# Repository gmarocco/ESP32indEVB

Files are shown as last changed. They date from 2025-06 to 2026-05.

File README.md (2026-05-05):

# ESP32indEVB
ESP32-S3 industrial development board

This board is based on ESP32-S3 chip and microcontoller
 - There are the following physical communication interfaces
   
 a) debug USB (it is connected to a UARTport of ESP32-S3)  
 
 b) native USB 
 
 c) isolated CANBUS with termination resistor 
 
 d) isolated RS485 with termination resistor 
 
 - There is a 9 RGB LED matrix (WS2812B) 
 
- There are 9 ESD protected GPIOs 

 - There is a free section of testpoints for experiment 

This is the third version of the board. With respect to the second version, some nets have been renamed and stiching vias along the board perimeter have been added

  You can open and modify the project with KiCad 9 release 
  For questions, feedback or proposals you can contact me at the following email: info@pcbsemplice.com
  
 !!! It is not allowed to reproduce the board for mass production and for business purposes. If you have a business proposal you can write at the following email: info@pcbsemplice.com
 
  Are you interested in these projects and want to contribute to the development of boards and projects (including open-source), prototypes, and documentation? You can make a no-obligation donation at this PayPal link: https://shorturl.at/0LquK Every contribution, no matter how small, makes a difference. Thank you!

Scheda di sviluppo industriale ESP32-S3  
Questa scheda è basata sul chip e microcontrollore ESP32-S3 

- Sono presenti le seguenti interfacce di comunicazione fisica:
  
a) USB di debug (collegata a una porta UART dell'ESP32-S3)  

b) USB nativa 

c) CANBUS isolato con resistenza di terminazione 

d) RS485 isolata con resistenza di terminazione 

- È presente una matrice di 9 LED RGB (WS2812B)

- Sono presenti 9 GPIO con protezione ESD  

- È disponibile una sezione gratuita di testpoint per esperimenti  
È possibile aprire e modificare il progetto con KiCad versione 9  

Questa è la terza verione della scheda. Rispetto alla seconda versione sono state rinominate alcune net e sono stati aggiunti dei fori di via stiching lungo il perimetro della scheda

Per domande feedback e suggerimenti mi puoi contattare al seguente indirizzo email: info@pcbsemplice.com

!!! E' vietato riprodurre la scheda per scopi commerciali. Per proposte commerciali puoi scrivere a info@pcbsemplice.com

Se parli Italiano e stai inziando con KiCad ti segnalo il percorso KiCadSemplice (www.pcbsemplice.com/kicad)
Se sei interessato a progettare circuiti professionali , è disponibile un percorso personalizzato chiamato pcb-pro-accademy 
  -  ESP32_industrial EVB 3D model
  -  block diagram
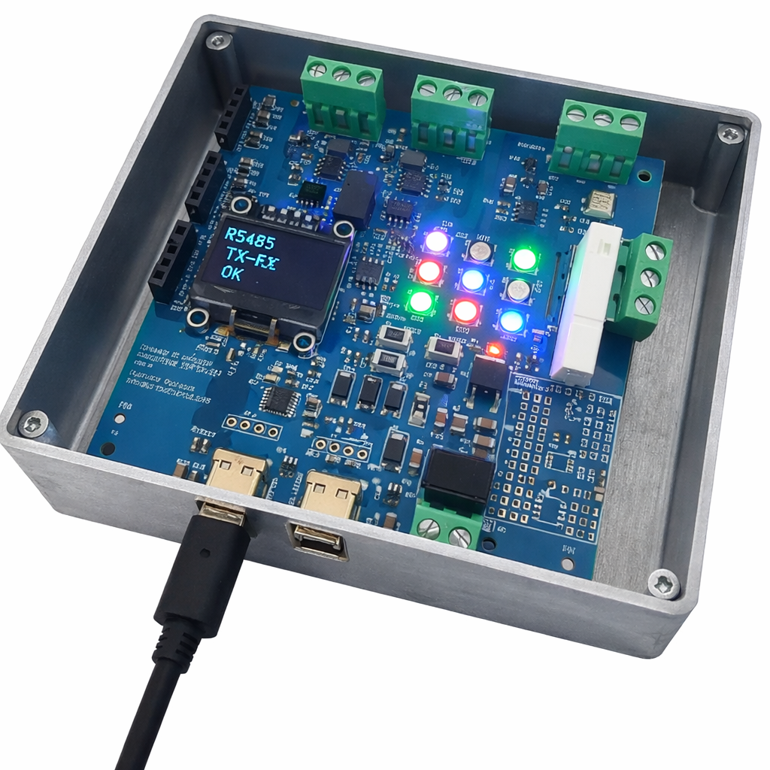
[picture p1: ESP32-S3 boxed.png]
  -  

Ti interessano questi progetti e vuoi contribuire per lo sviluppo di schede e progetti (anche open-source), prototipi, documentazione ? Puoi effettuare una donazione senza impegno a questo link di Paypal https://shorturl.at/0LquK Ogni contributo, anche piccolo, fa la differenza. Grazie!

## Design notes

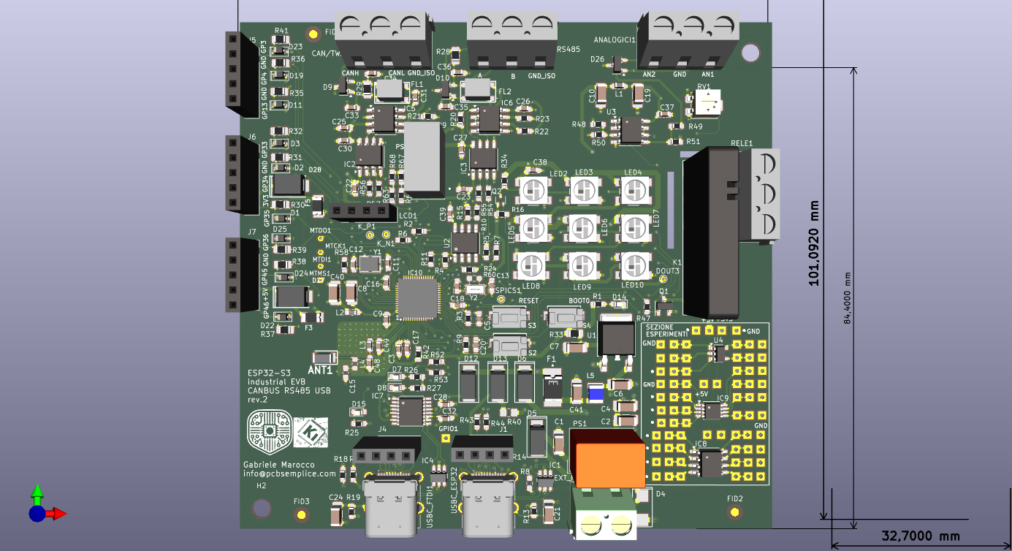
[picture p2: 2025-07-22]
3D ESP32-S3 industrial dev.board.png

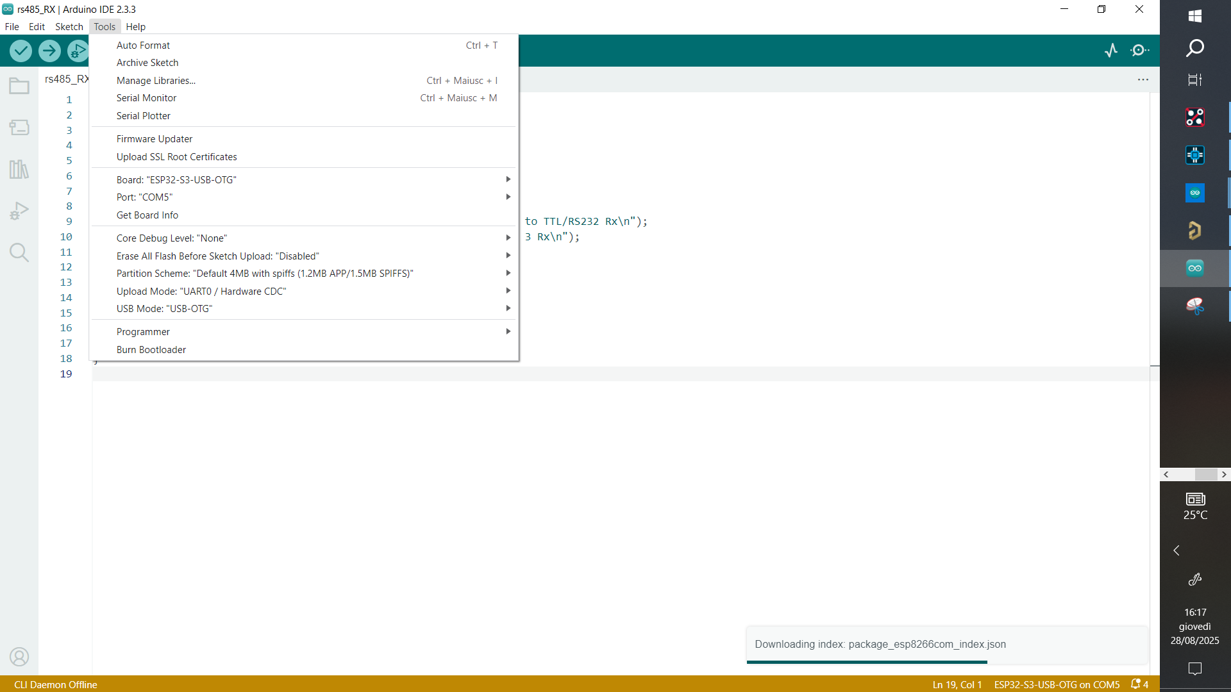
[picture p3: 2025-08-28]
Arduino examples/board configuration.png

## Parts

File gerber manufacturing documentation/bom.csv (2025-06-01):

Designator | Footprint | Quantity | Value | LCSC Part #
ANALOGICI1, CAN1, RELE1, RS1 | TerminalBlock_bornier-3_P5.08mm | 4 | 282837-3
ANT1 | ANTC3216X130N | 1 | RFANT3216120A5T
C1, C2, C4 | 1206 | 3 | 10uF_50V
C10, C19, C40, C41, C6, C7, C8 | 1206 | 7 | 10uF 50V
C11, C12 | 0603 | 2 | 20pF
C13, C14 | 0603 | 2 | 30pF
C15, C48, C49 | 0603 | 3 | 1p8F
C16, C17, C18, C20, C22, C23, C25, C26, C27, C28, C29, C3, C30, C32, C37, C38, C39, C9 | 0603 | 18 | 100nF
C21, C24 | 1206 | 2 | 3n3F 1kV
C31, C33, C34, C35, C36 | 0603 | 5 | 100PF
C5 | 0603 | 1 | 1uF
D1, D11, D19, D2, D22, D23, D24, D25, D3 | SOD-323 | 9 | ESD7351HT1G
D10, D26, D9 | SOT-23-3 | 3 | PESD2CANFD27L-TR
D12, D13, D5, D6 | SMA | 4 | CDBA340-HF
D14, D15, D7, D8 | 0603 | 4 | LED
D27 | DIOM5436X244N | 1 | SMBJ5.0A
D28 | DIOM5436X244N | 1 | SMBJ3V3-E3/5B
D4 | DIOM5436X261N | 1 | SMBJ36CA
DOUT3, K_N1, K_P1, MTCK1, MTDI1, MTDO1, MTMS1, SPICS1 | TestPoint_THTPad_D1.0mm_Drill0.5mm | 8 | TestPoint
EXT_POWER1 | 2828372 | 1 | 282837-2
F1 | 1812L010DR | 1 | 1812L150_24MR
F3, F5 | 1206L05015YR | 2 | 1206L050_15YR
FID1, FID2, FID3 | Fiducial_1.5mm_Mask3mm | 3 | Fiducial
FL1, FL2 | ACT45B1012PTL003 | 2 | ACT45B-101-2P-TL003
H1, H2 | MountingHole_3.2mm_M3 | 2 | MountingHole
IC1, IC4 | SOT23-6 | 2 | USBLC6-2SC6
IC10 | QFN40P700X700X90-57N-D | 1 | ESP32-S3FN8
IC2, IC3 | SO-8_3.9x4.9mm_P1.27mm | 2 | ADUM3201ARZ-RL7
IC5 | SO-8_3.9x4.9mm_P1.27mm | 1 | MCP2562-E_SN
IC6 | SO-8_3.9x4.9mm_P1.27mm | 1 | MAX13488EESA+T
IC7 | TSSOP-16_4.4x5mm_P0.65mm | 1 | FT230XS-R
IC8 | SO-8_3.9x4.9mm_P1.27mm | 1 | NE555DR
IC9 | MSOP-8_3x3mm_P0.65mm | 1 | NE555DR
J1, J4 | PinHeader_1x04_P2.54mm_Vertical | 2 | Conn_01x04_Pin
J5, J6, J7 | PinSocket_1x05_P2.54mm_Vertical | 3 | Conn_01x05_Socket
K1 | Relay_SPDT_Finder_34.51_Vertical | 1 | FINDER-34.51
L1, L2 | 0603 | 2 | BLM18AG102SN1D
L3, L4 | 0603 | 2 | 2n4H
L5 | 1277ASH100MP2 | 1 | DFE322512F-4R7M=P2
LCD1 | PinHeader_1x04_P2.54mm_Vertical | 1 | SSD1306
LED10, LED2, LED3, LED4, LED5, LED6, LED7, LED8, LED9 | WS2812B | 9 | WS2812B
PS1 | Converter_DCDC_TRACO_TSR-1_THT | 1 | TSR_1-2450
PS2 | TEA10505 | 1 | TEA_1-0505
Q1 | SOT-23-3 | 1 | DRDC3105F-7
Q2 | SOT-523 | 1 | DMG1012T
R1, R20, R22, R23 | 0603 | 4 | 1K
R10, R11, R2, R24, R43, R44, R47, R52, R53, R54, R55, R56, R57, R58, R6, R63, R64, R7 | 0603 | 18 | 0R
R12, R14, R17, R18 | 0603 | 4 | 5k1
R13, R19 | 0603 | 2 | 1M
R15, R3, R4, R42, R5, R9 | 0603 | 6 | 100K
R16 | 0603 | 1 | 2k2
R21, R25, R26, R27 | 0603 | 4 | 470R
R28, R29 | 0805 | 2 | 120R
R30, R31, R32, R35, R36, R37, R38, R39, R41 | 0805 | 9 | 49R9
R33, R40 | 0805 | 2 | 0R 0.5W 0805
R34, R50, R51 | 0603 | 3 | 4k7
R48, R49 | 0603 | 2 | 47k
R60 | 0603 | 1 | 5M
R67, R68, R8 | 0603 | 3 | 1k5
RV1 | Potentiometer_Bourns_3314G_Vertical | 1 | 10k
S2, S3, S4 | EVQPE104K | 3 | EVQ-PE104K
TP1, TP10, TP11, TP12, TP13, TP14, TP15, TP16, TP17, TP18, TP19, TP2, TP20, TP21, TP22, TP23, TP24, TP25, TP26, TP27, TP28, TP29, TP3, TP30, TP31, TP32, TP33, TP34, TP35, TP36, TP37, TP38, TP39, TP4, TP40, TP41, TP42, TP43, TP44, TP45, TP46, TP47, TP48, TP49, TP5, TP50, TP51, TP52, TP53, TP54, TP55, TP56, TP57, TP58, TP59, TP6, TP60, TP61, TP62, TP63, TP64, TP65, TP66, TP67, TP68, TP69, TP7, TP70, TP71, TP72, TP8, TP9 | TestPoint_Pad_through hole 1.5mm | 72 | TestPoint
U1 | TO-252-2 | 1 | NCP1117-3.3_TO252
U2 | SOIC-8_3.9x4.9mm_P1.27mm | 1 | W25Q80DVSNIG
U3 | SO-8_3.9x4.9mm_P1.27mm | 1 | LMV358IDR
U4 | SOT-23-5 | 1 | NCP718xSN180
USBC_ESP32, USBC_FTDI1 | UJ31CHG2SMTTR | 2 | UJ31-CH-G2-SMT-TR
Y1 | FL4000157Z | 1 | FL4000157Z
Y2 | ABS07AIG | 1 | ABS07AIG-32.768KHZ-D-T

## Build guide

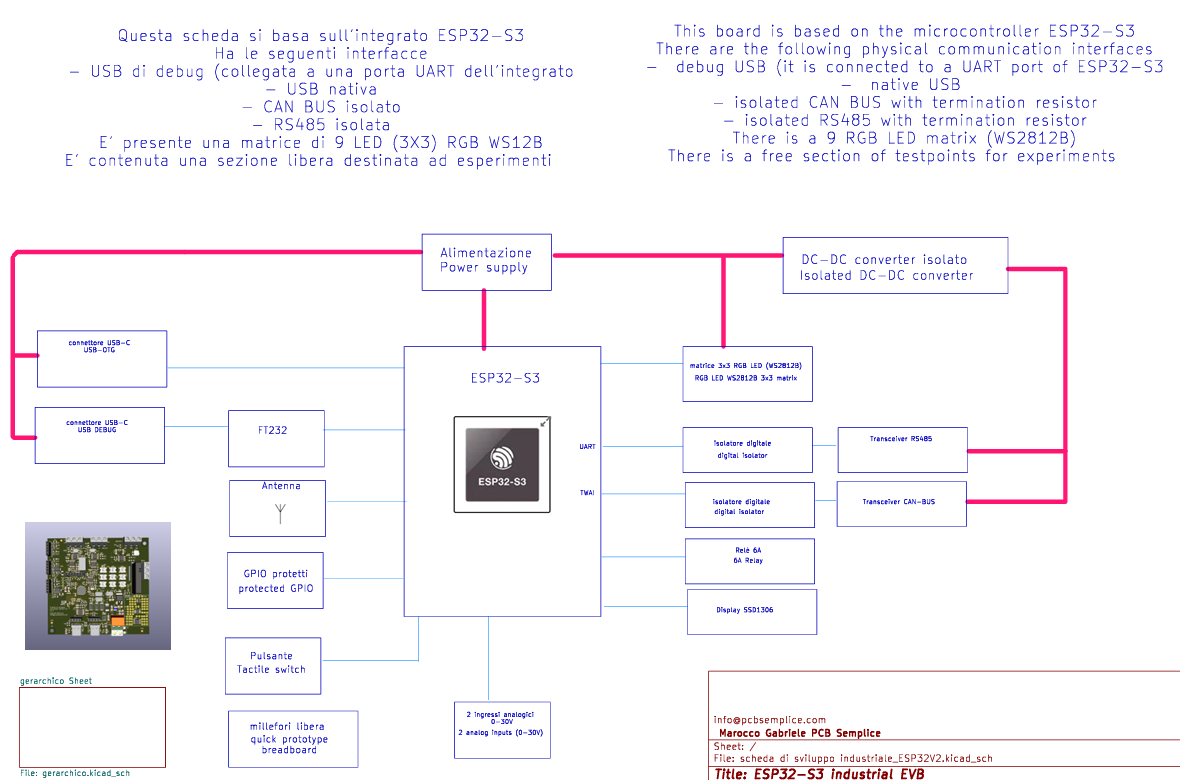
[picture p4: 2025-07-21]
gerber manufacturing documentation/block diagram.png

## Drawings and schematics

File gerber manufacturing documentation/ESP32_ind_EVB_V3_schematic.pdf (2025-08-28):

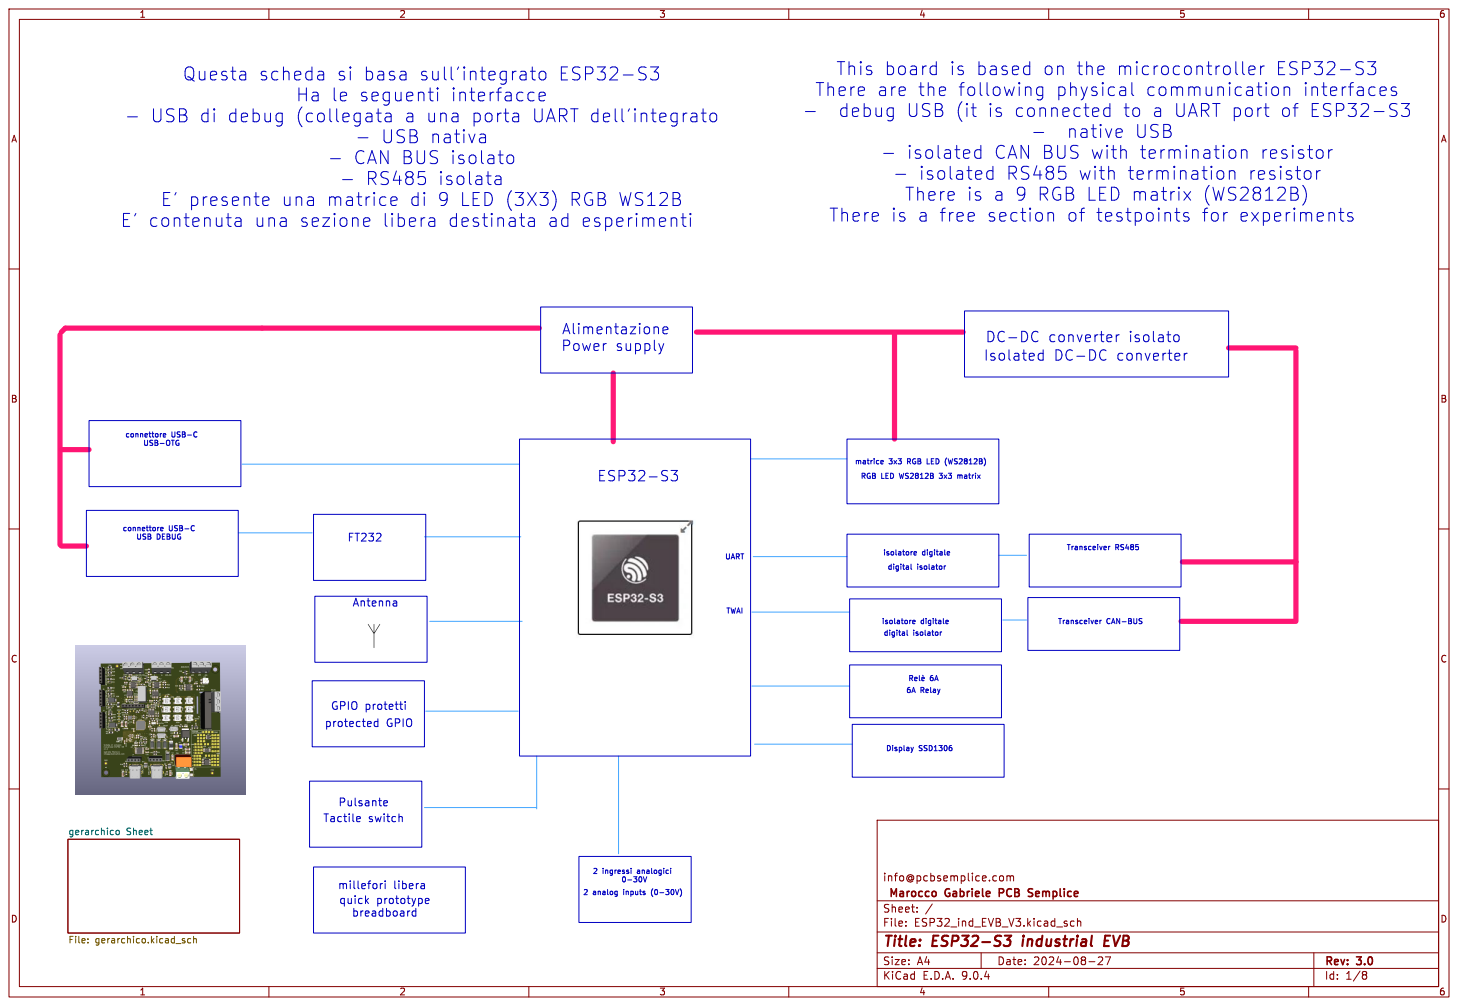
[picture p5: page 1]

- debug USB (it is connected to a UART port of ESP32-S3

There is a 9 RGB LED matrix (WS2812B)

DC-DC converter isolato

þÿRelè6A Power supply Antenna

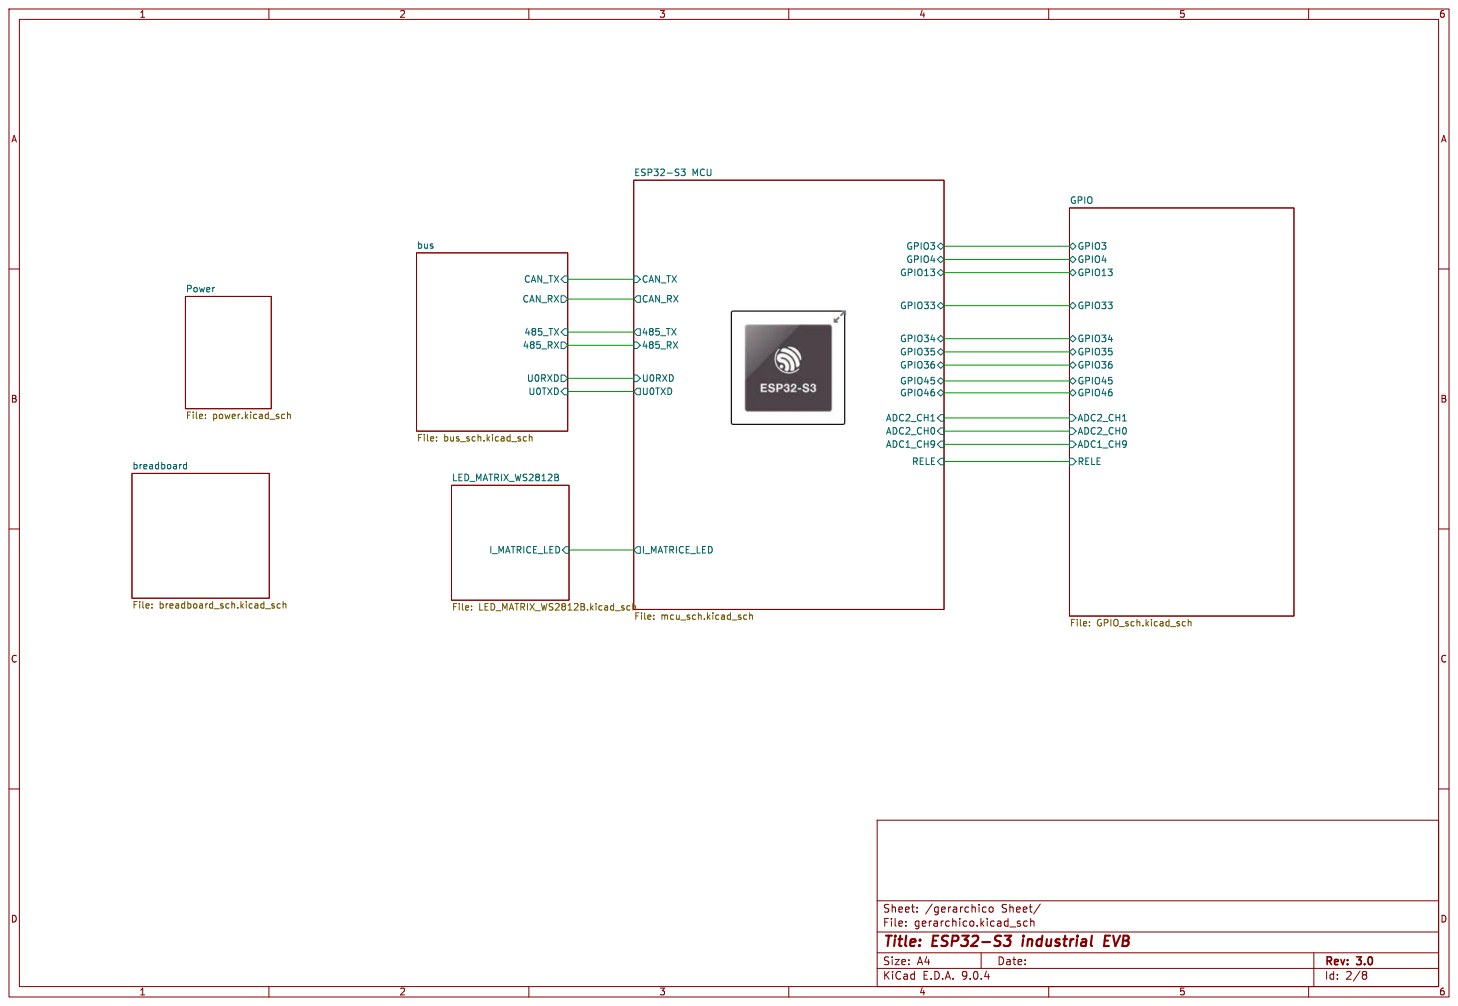
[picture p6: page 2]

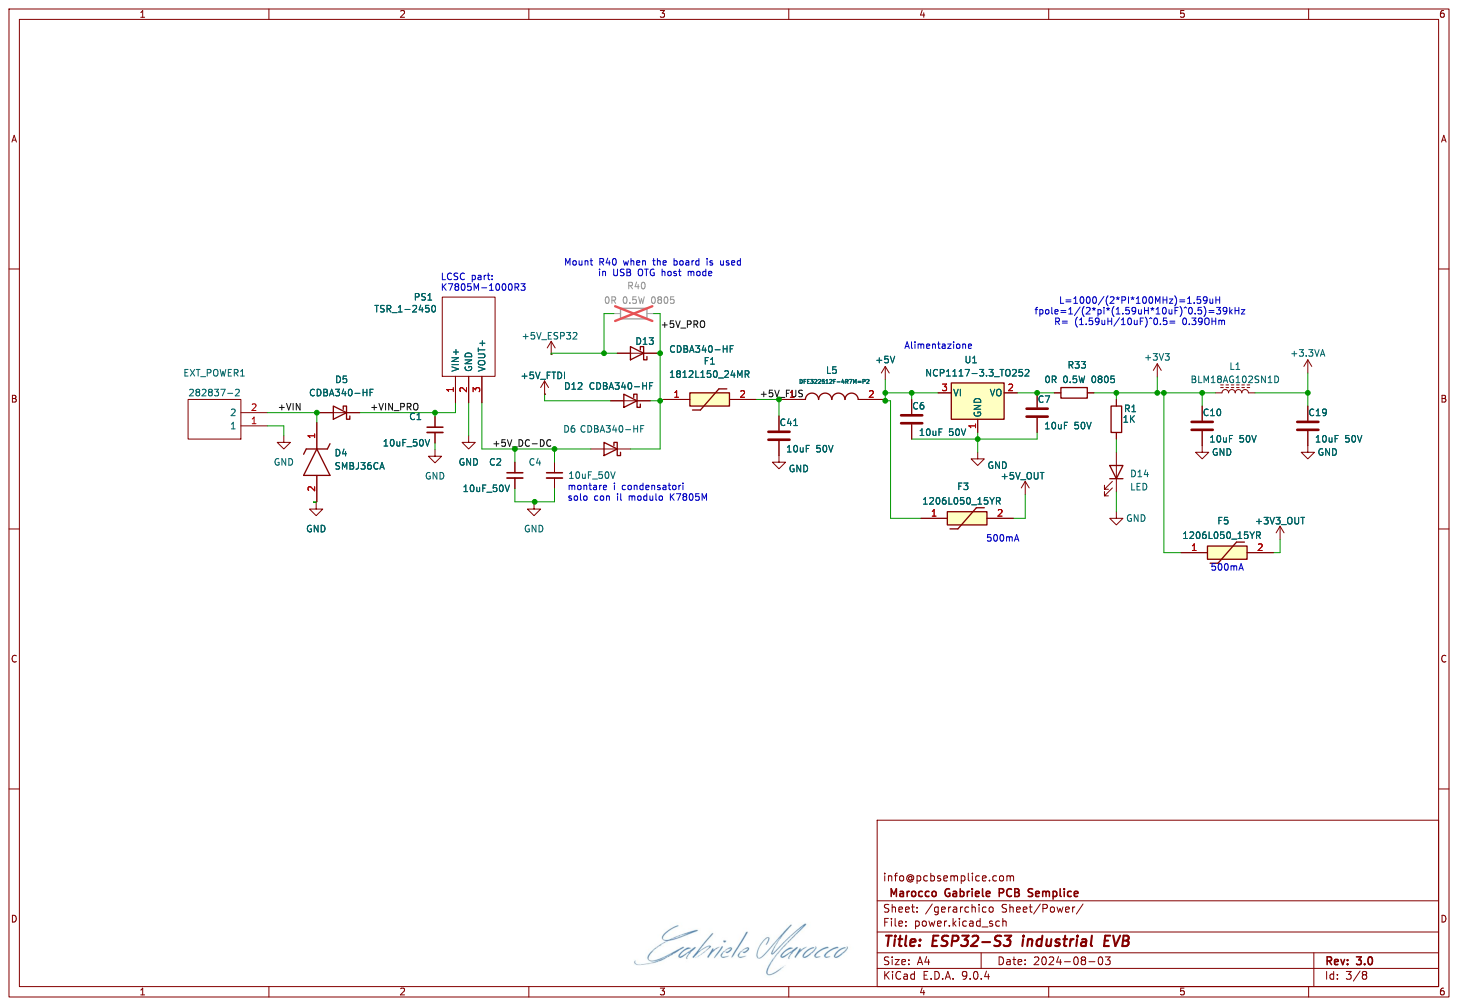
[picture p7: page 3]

500mA Mount R40 when the board is used
+5V_ESP32 C4

in USB OTG host mode

montare i condensatori solo con il modulo K7805M

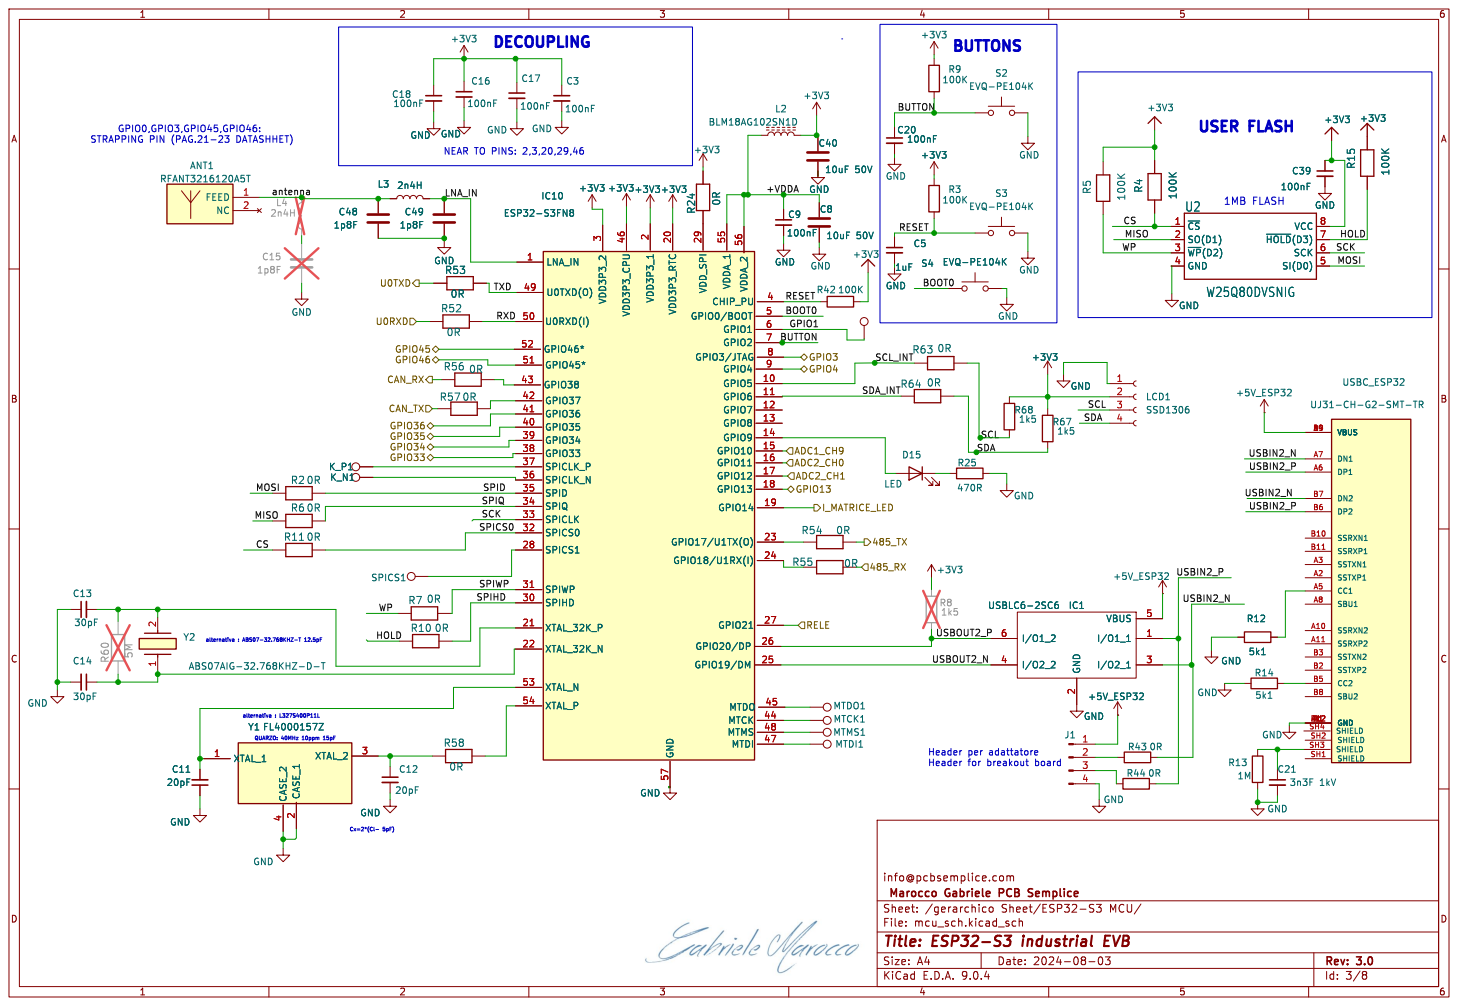
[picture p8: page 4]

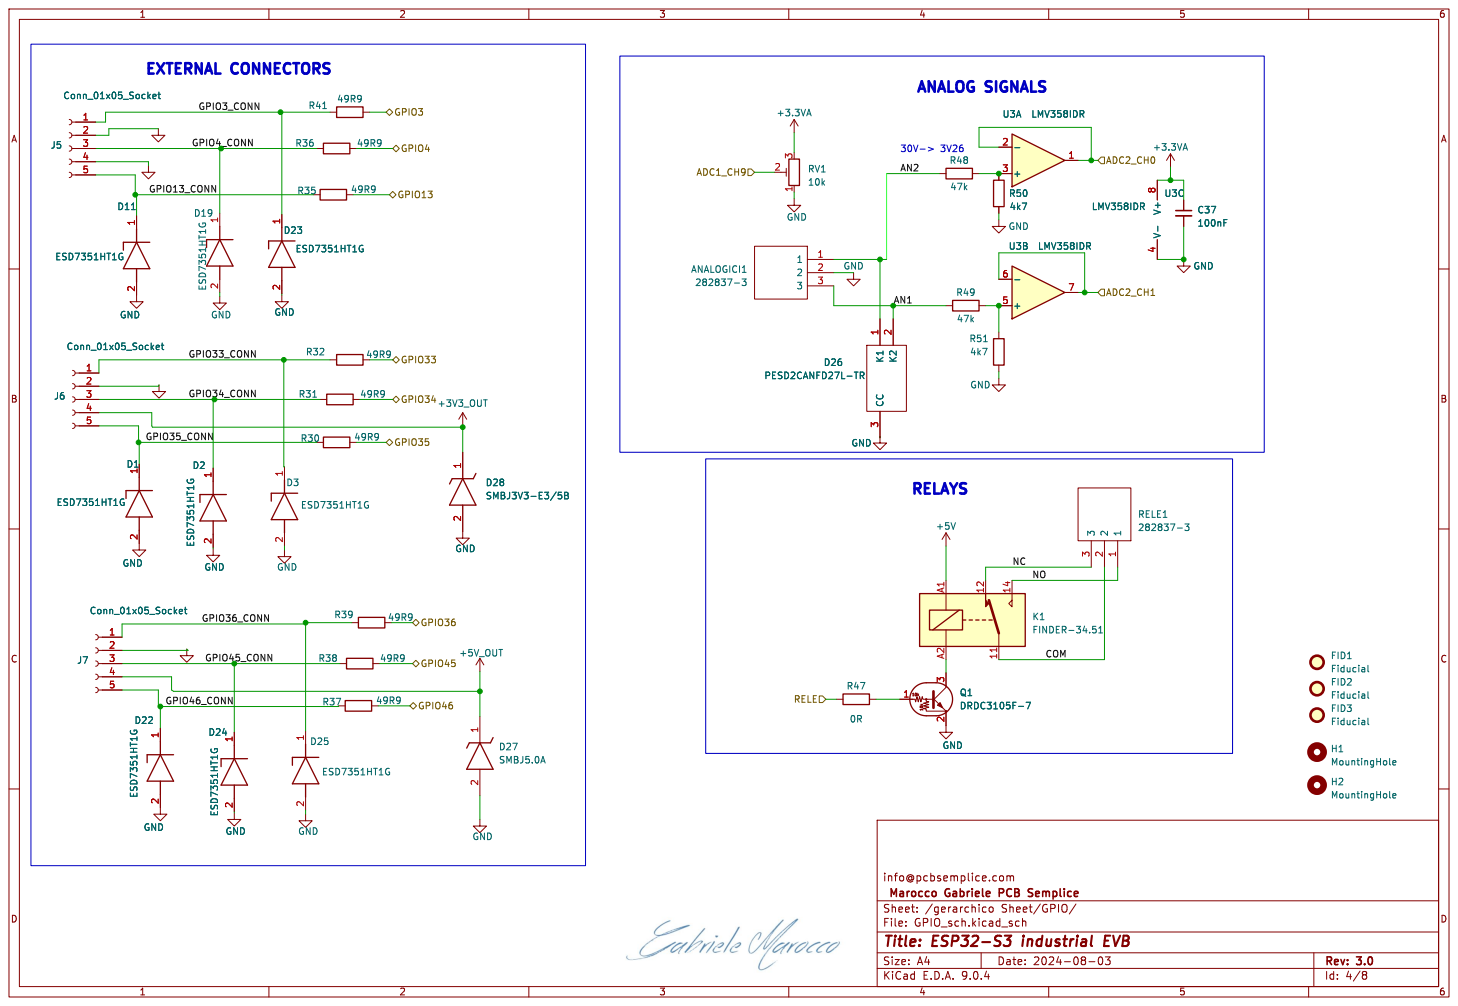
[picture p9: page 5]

FID2 Fiducial H1 MountingHole FID1 Fiducial H2 MountingHole FID3 Fiducial

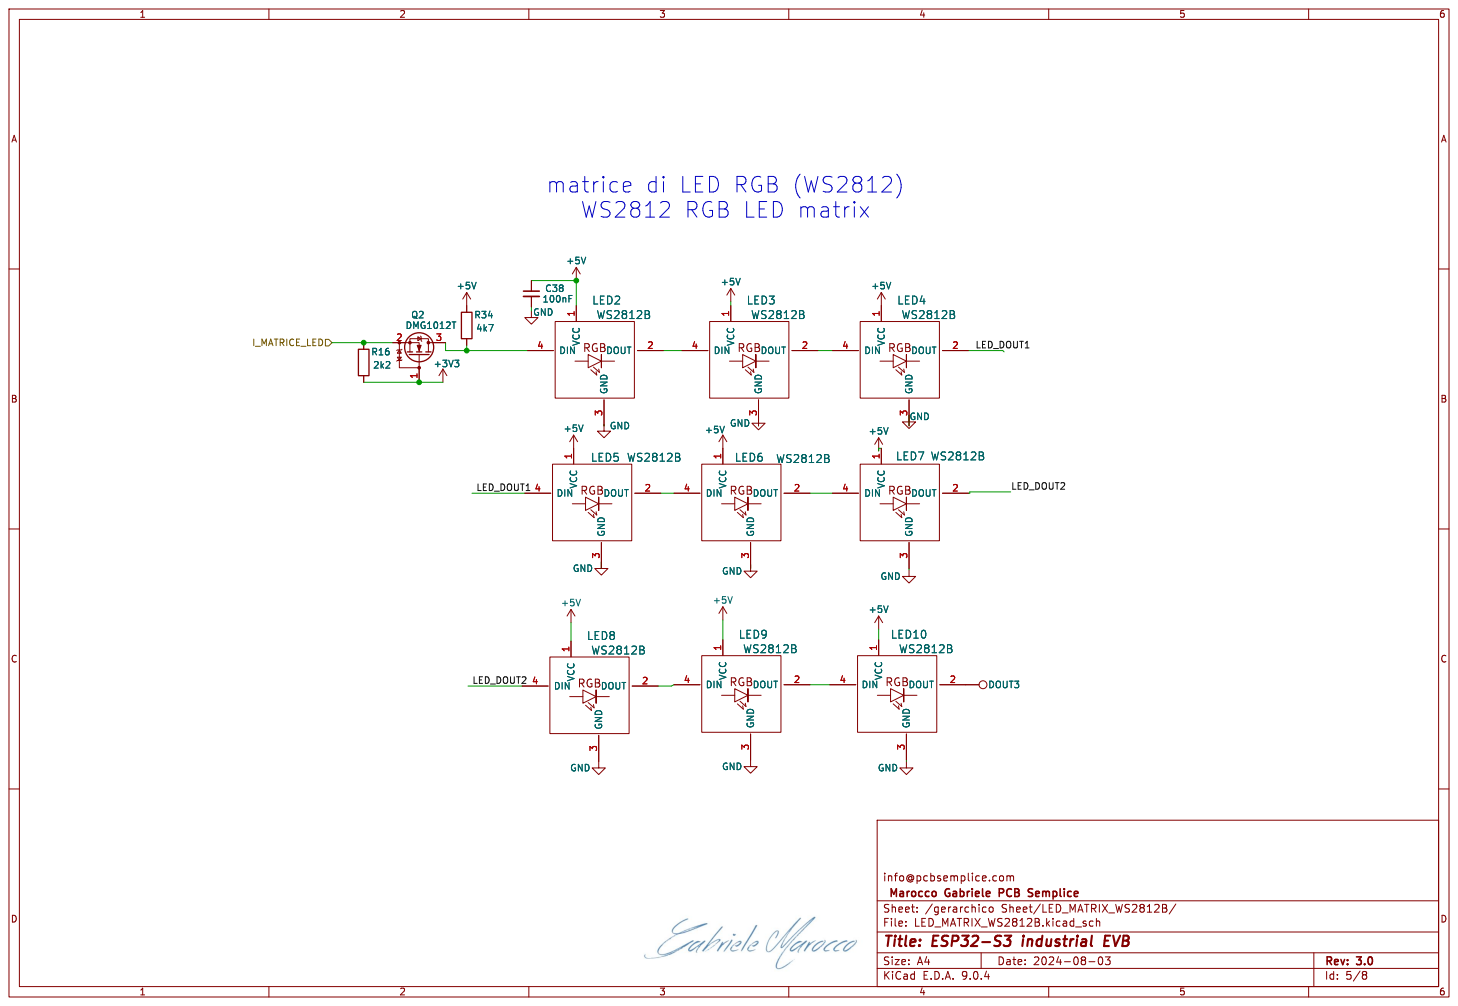
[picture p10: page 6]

LED_DOUT1 matrice di LED RGB (WS2812)
WS2812 RGB LED matrix

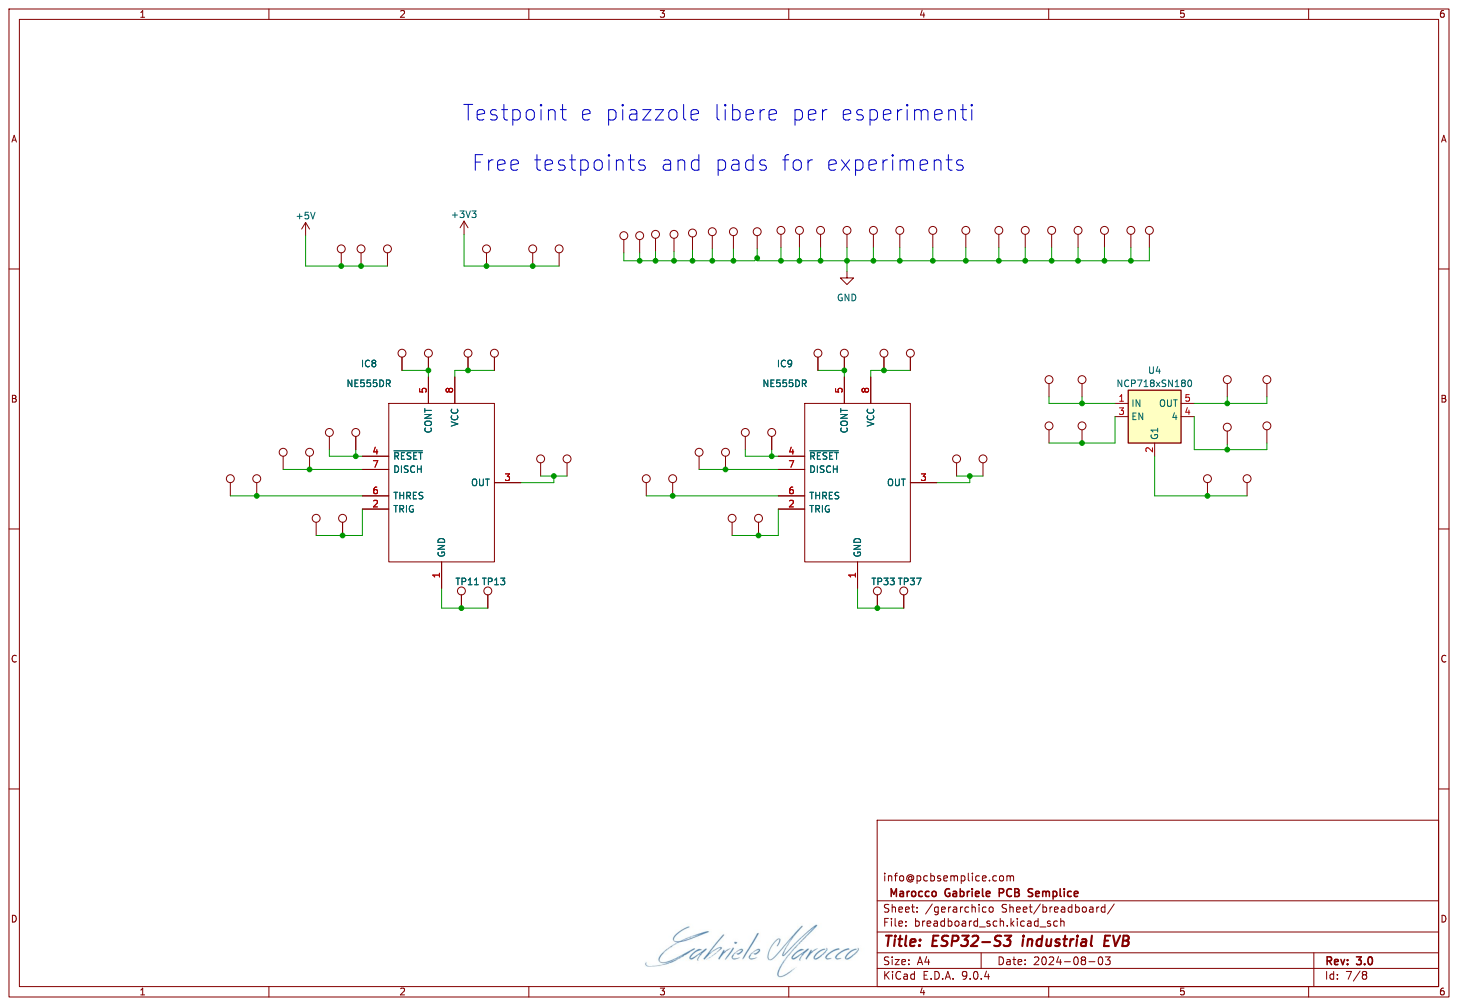
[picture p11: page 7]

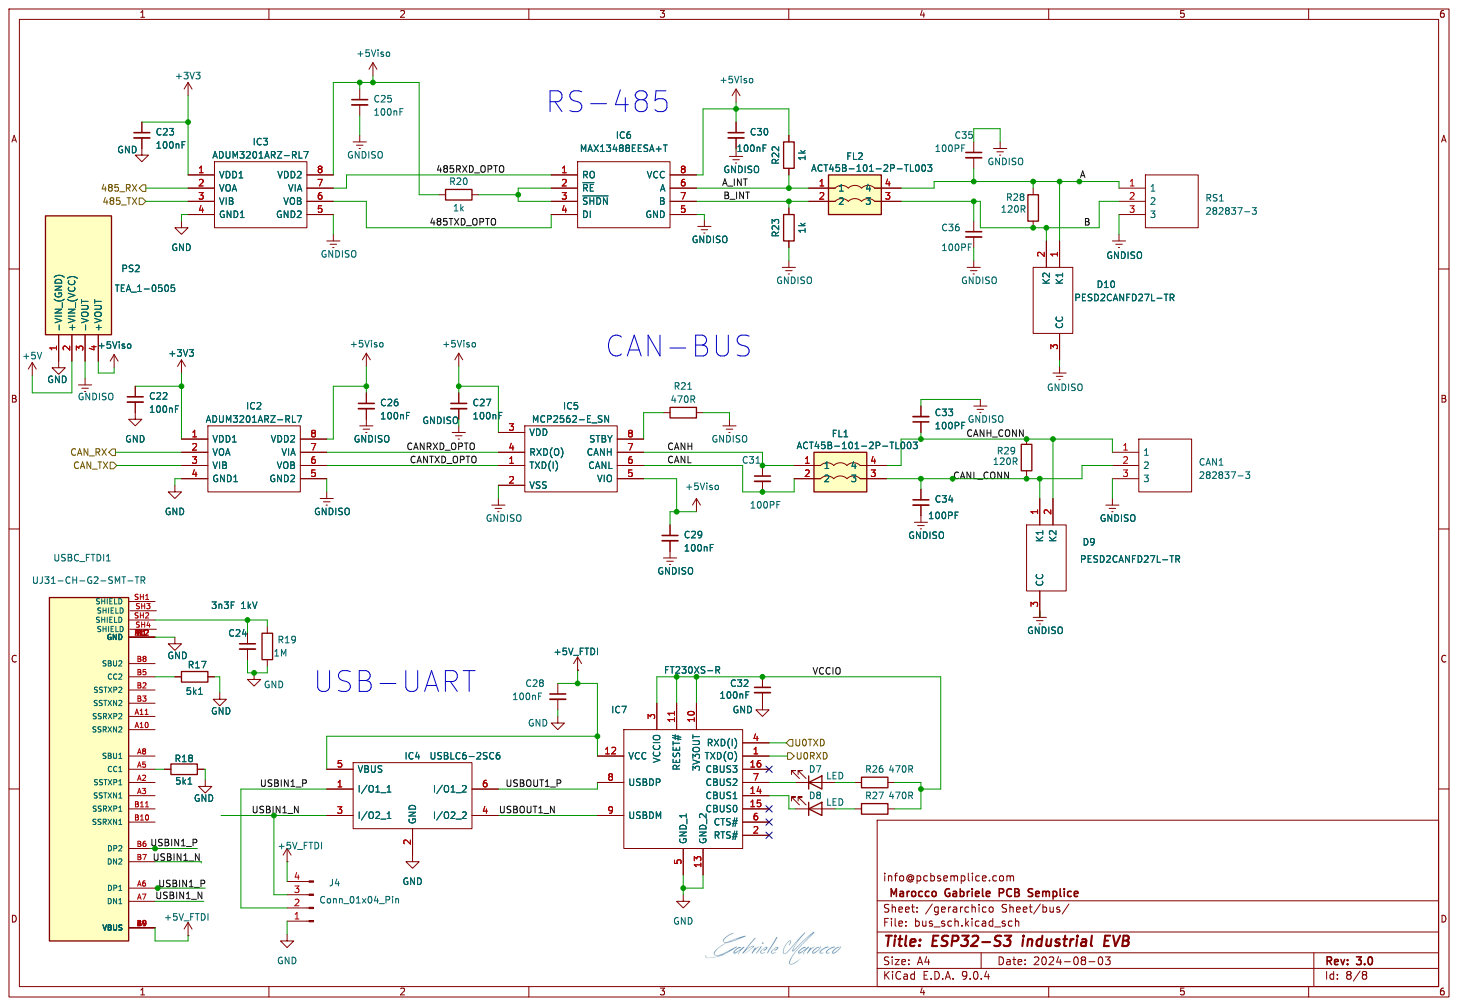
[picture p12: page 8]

5 3V3OUT 10 GND_2 13 CBUS3 16 CBUS2 7 CBUS1 14 CBUS0 15 CTS# 6 RTS# 2 RESET# 11 RXD(I) 4 TXD(O) 1 C32

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

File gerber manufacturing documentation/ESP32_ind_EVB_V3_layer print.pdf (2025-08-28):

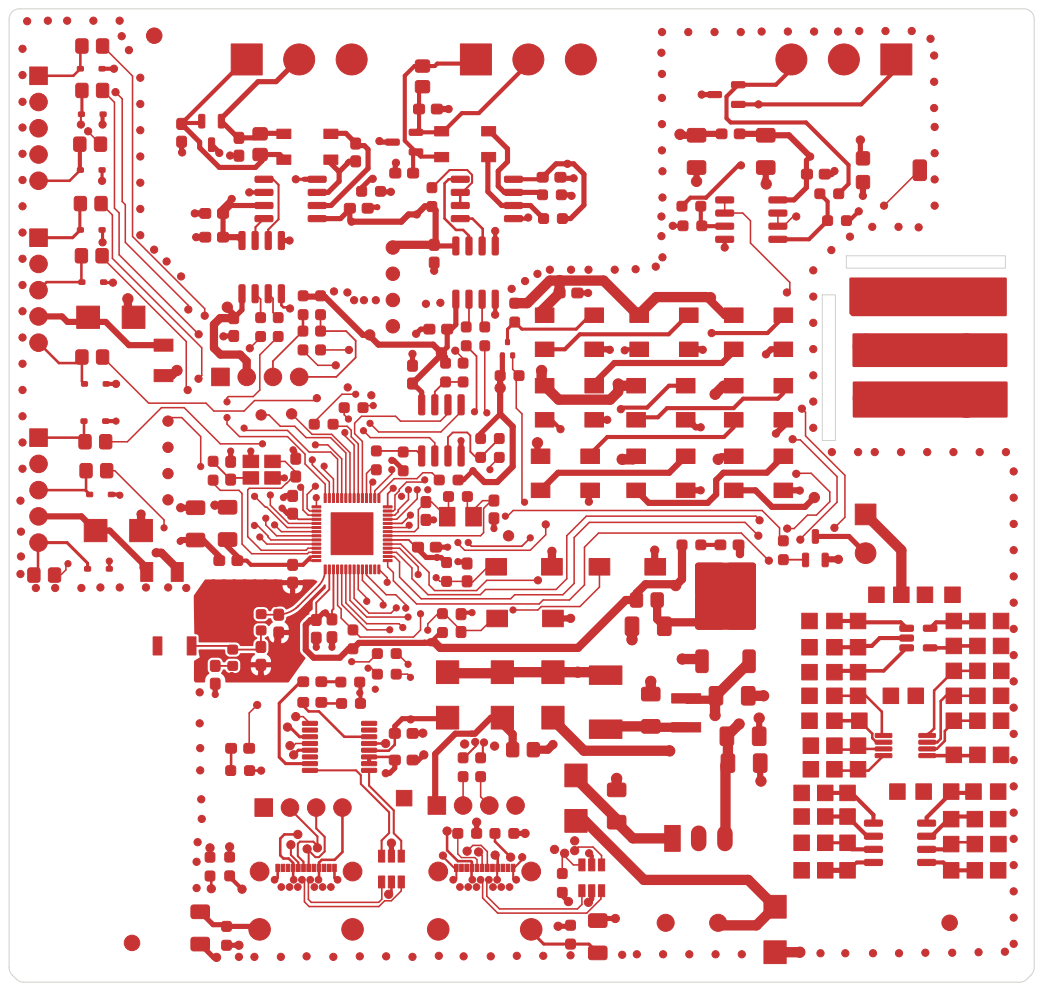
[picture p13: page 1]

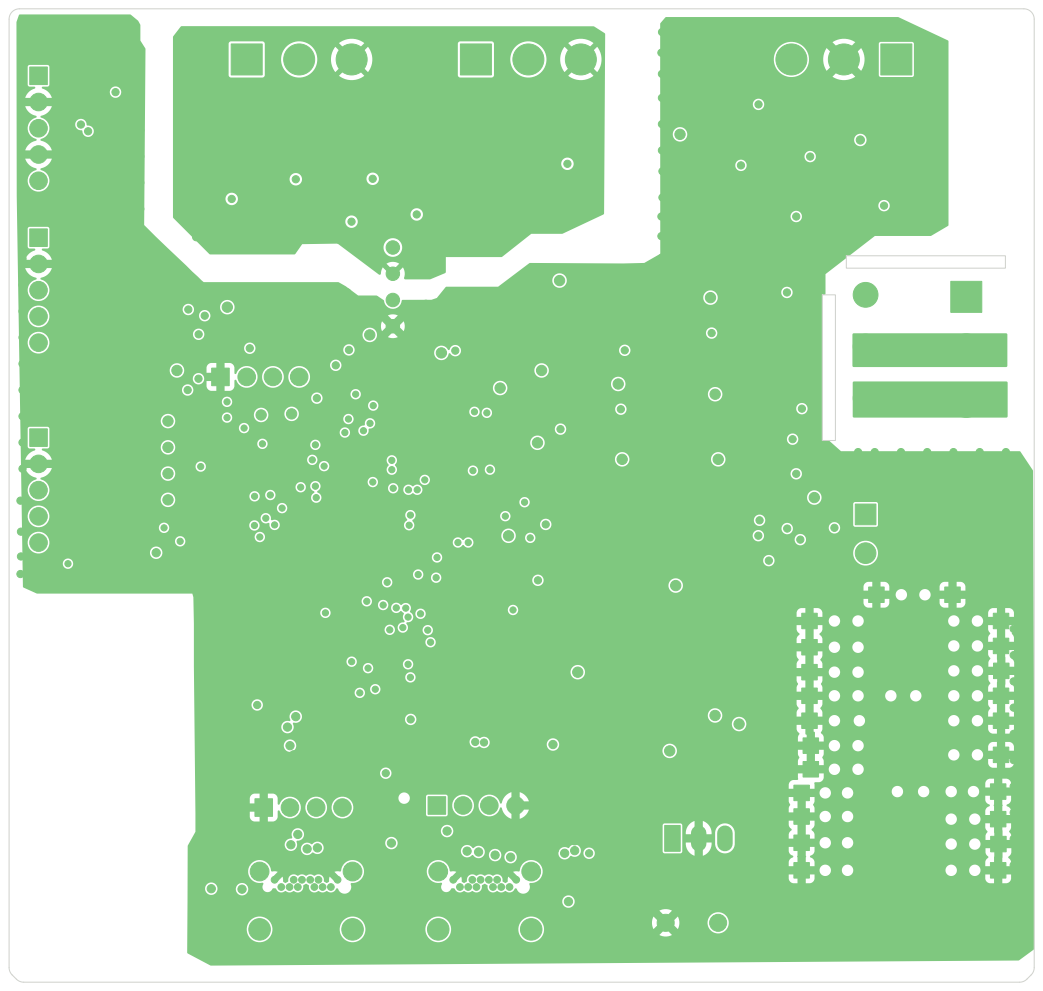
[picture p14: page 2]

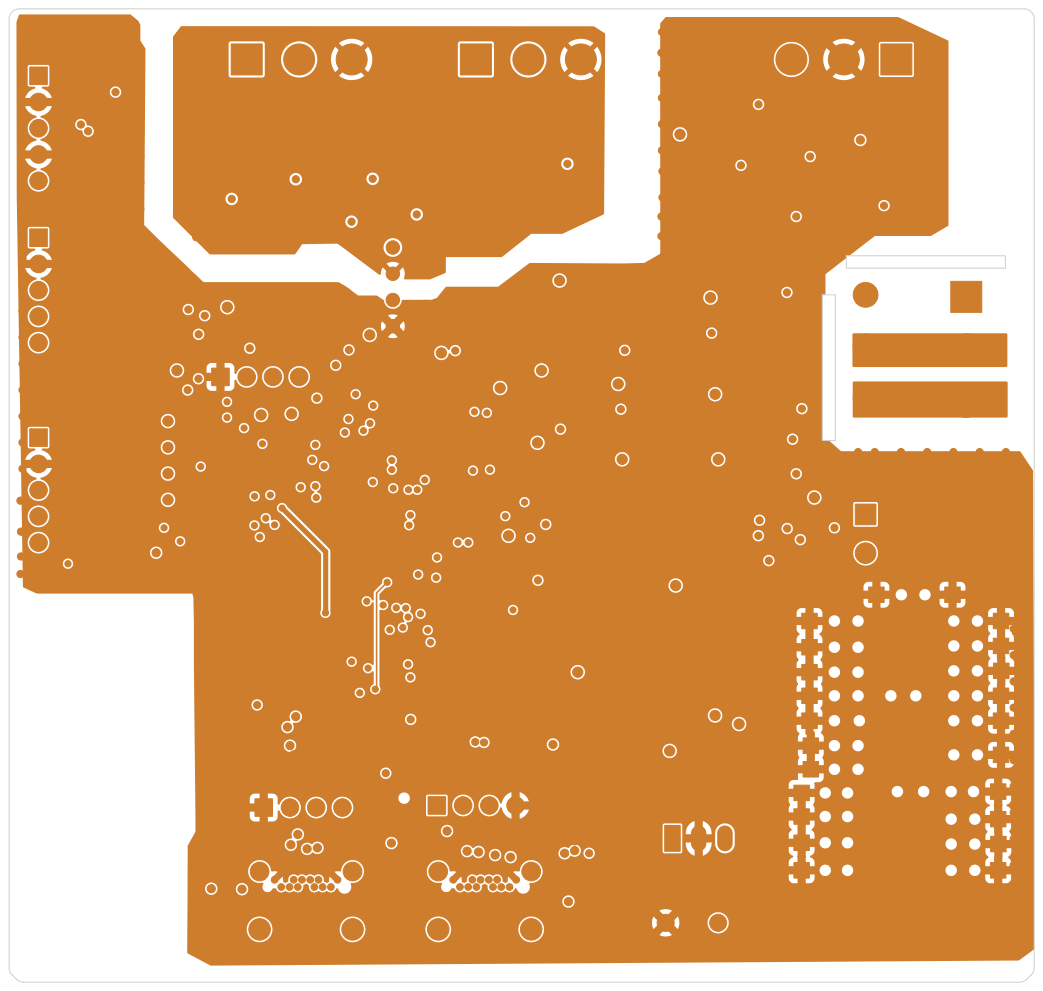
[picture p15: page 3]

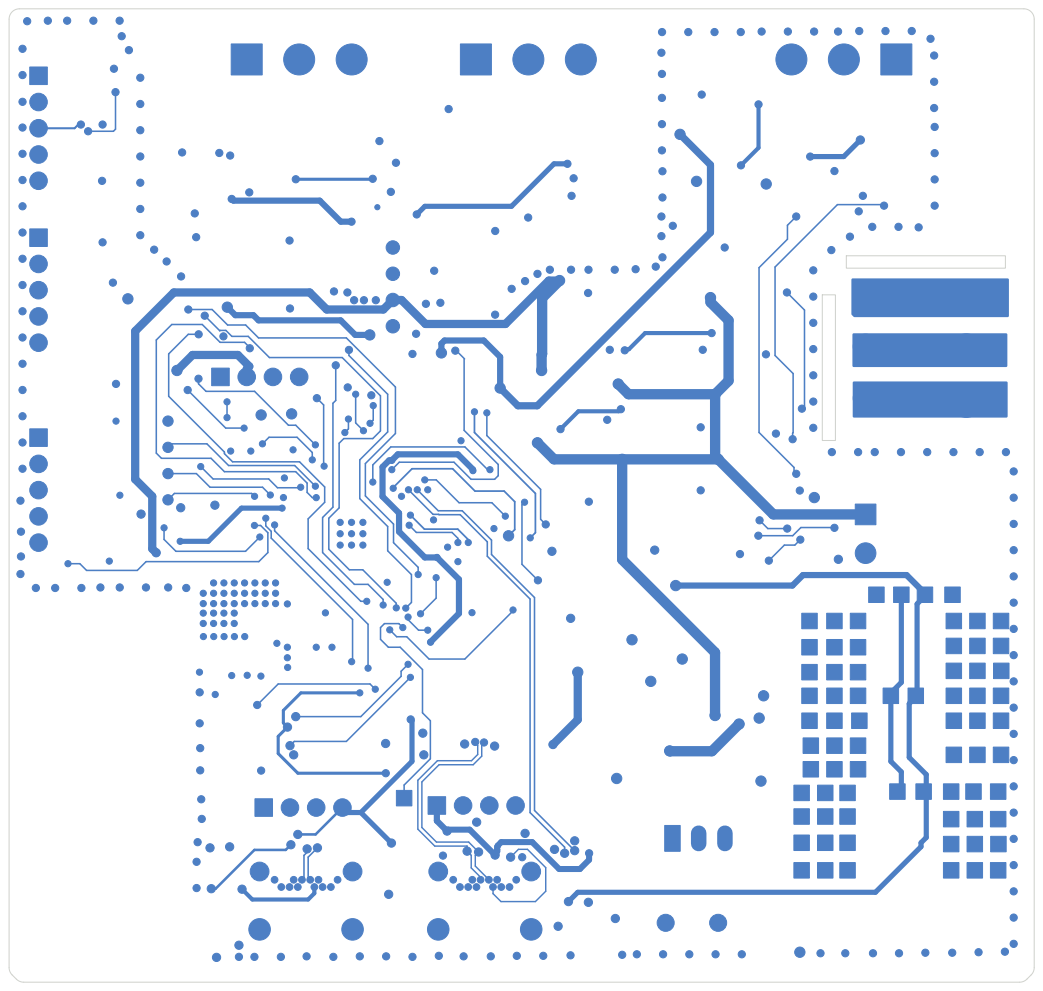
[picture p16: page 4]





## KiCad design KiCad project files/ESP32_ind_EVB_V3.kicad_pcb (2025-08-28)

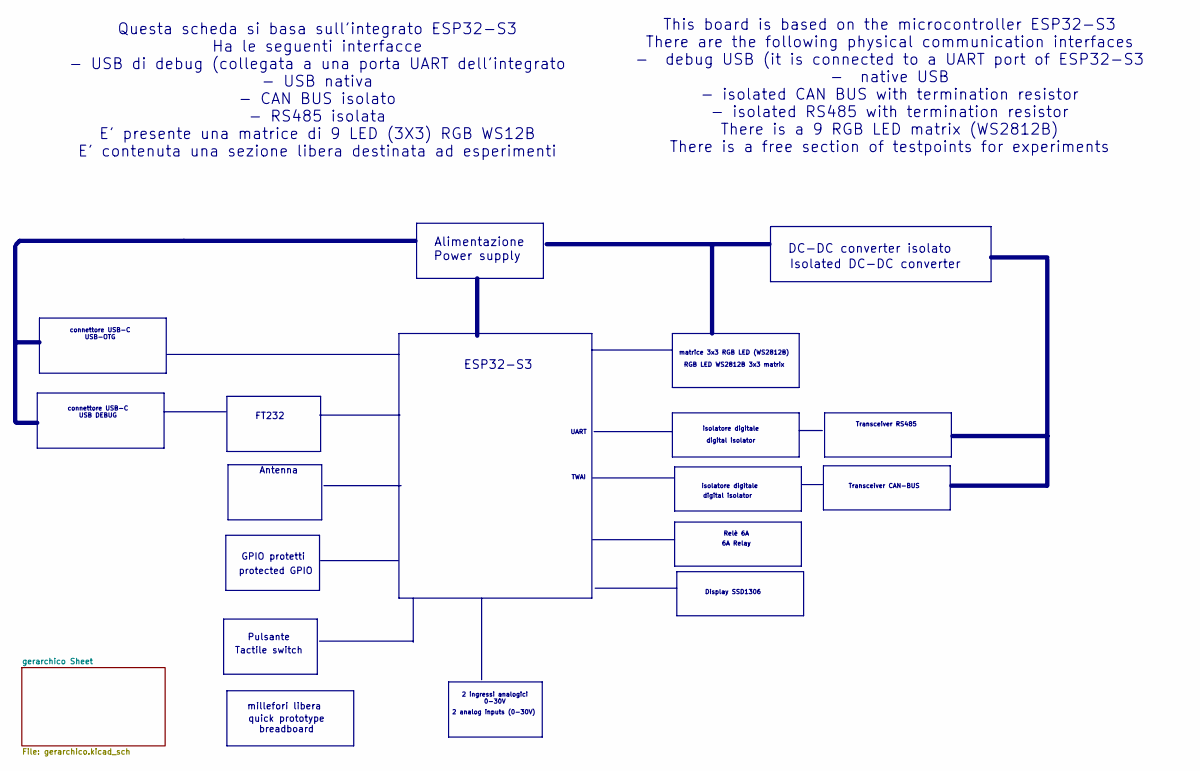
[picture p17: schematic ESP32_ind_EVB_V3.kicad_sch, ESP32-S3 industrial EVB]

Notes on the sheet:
TWAI
FT232
isolatore digitale
Transceiver RS485
matrice 3x3 RGB LED (WS2812B)
This board is based on the microcontroller ESP32-S3 There are the following physical communication interfaces - debug USB (it is connected to a UART port of ESP32-S3 - native USB - isolated CAN BUS with termination resistor - isolated RS485 with termination resistor There is a 9 RGB LED matrix (WS2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
Alimentazione
GPIO protetti
ESP32-S3
Transceiver CAN-BUS
millefori libera
Power supply
quick prototype breadboard
Questa scheda si basa sull'integrato ESP32-S3 Ha le seguenti interfacce - USB di debug (collegata a una porta UART dell'integrato - USB nativa - CAN BUS isolato - RS485 isolata E' presente una matrice di 9 LED (3X3) RGB WS12B E' contenuta una sezione libera destinata ad esperimenti
6A Relay
digital isolator
Pulsante
connettore USB-C USB-OTG
DC-DC converter isolato
Display SSD1306
Isolated DC-DC converter
2 analog inputs (0-30V)
protected GPIO
RGB LED WS2812B 3x3 matrix
Antenna
Relè 6A
2 ingressi analogici 0-30V
connettore USB-C USB DEBUG
Tactile switch
UART

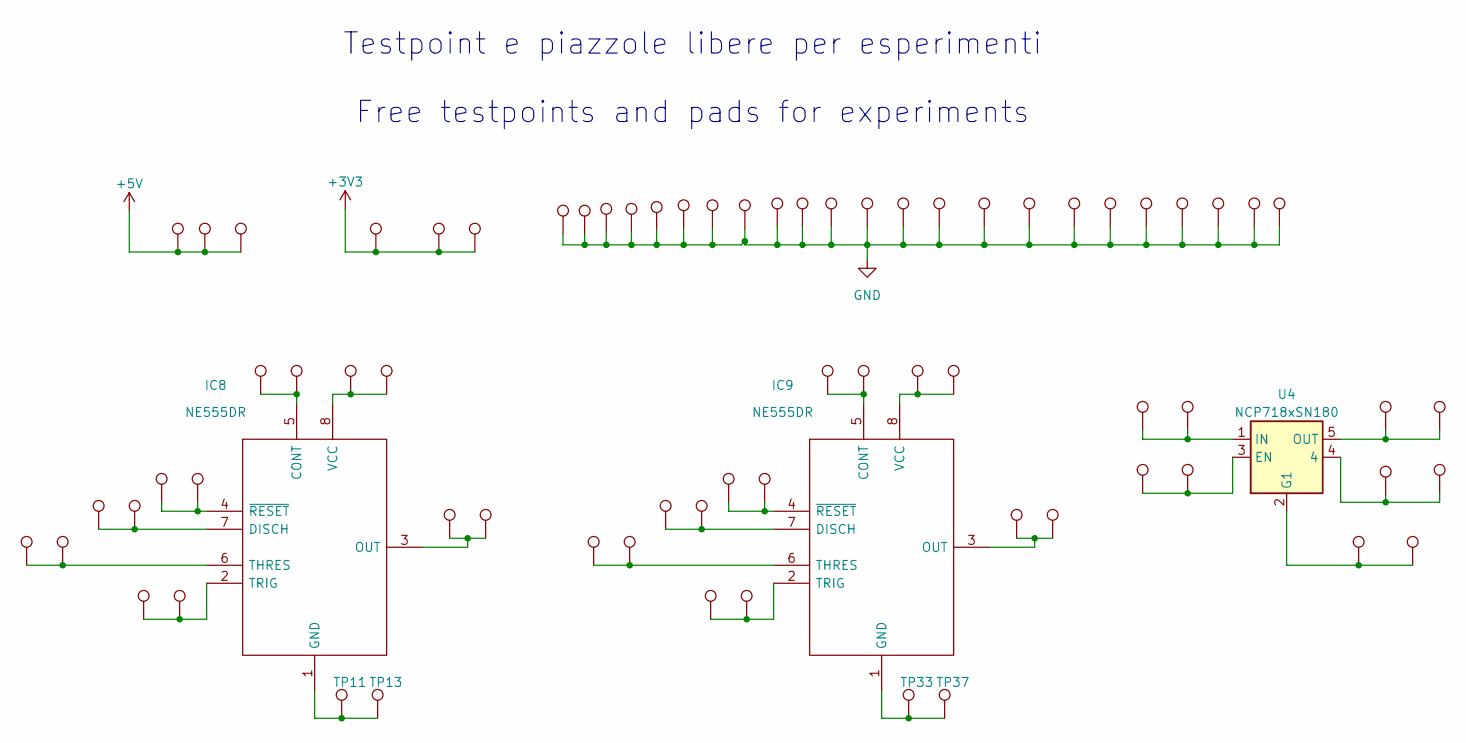
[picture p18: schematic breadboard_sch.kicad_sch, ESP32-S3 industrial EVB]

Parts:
IC8: NE555DR; SO-8_3.9x4.9mm_P1.27mm; Manufacturer_Part_Number NE555DR; Mouser Part Number 595-NE555DR
IC9: NE555DR; MSOP-8_3x3mm_P0.65mm; Manufacturer_Part_Number NE555DR; Mouser Part Number 595-NE555DR
TP1, TP2, TP3, TP4, TP5, TP6, TP7, TP8, TP9, TP10, TP11, TP12, TP13, TP14, TP15, TP16, TP17, TP18, TP19, TP20, TP21, TP22, TP23, TP24, TP25, TP26, TP27, TP28, TP29, TP30, TP31, TP32, TP33, TP34, TP35, TP36, TP37, TP38, TP39, TP40, TP41, TP42, TP43, TP44, TP45, TP46, TP47, TP48, TP49, TP50, TP51, TP52, TP53, TP54, TP55, TP56, TP57, TP58, TP59, TP60, TP61, TP62, TP63, TP64, TP65, TP66, TP67, TP68, TP69, TP70, TP71: TestPoint; TestPoint_Pad_through hole 1.5mm
U4: NCP718xSN180; SOT-23-5

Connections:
+3V3: TP25.1, TP29.1, TP30.1; also elsewhere on the board
+5V: TP17.1, TP18.1, TP19.1; also elsewhere on the board
GND: TP34.1, TP36.1, TP38.1, TP40.1, TP41.1, TP43.1, TP45.1, TP46.1, TP47.1, TP50.1, TP51.1, TP54.1, TP55.1, TP56.1, TP57.1, TP59.1, TP63.1, TP66.1, TP67.1, TP68.1, TP69.1, TP70.1, TP71.1; also elsewhere on the board
unnamed: IC8.5 (CONT), TP9.1, TP10.1
unnamed: IC8.7 (DISCH), TP3.1, TP4.1
unnamed: IC8.1 (GND), TP11.1, TP13.1
unnamed: IC8.3 (OUT), TP15.1, TP16.1
unnamed: IC8.6 (THRES), TP1.1, TP2.1
unnamed: IC8.2 (TRIG), TP5.1, TP7.1
unnamed: IC8.8 (VCC), TP12.1, TP14.1
unnamed: IC8.4 (~RESET), TP6.1, TP8.1
unnamed: IC9.5 (CONT), TP31.1, TP32.1
unnamed: IC9.7 (DISCH), TP22.1, TP23.1
unnamed: IC9.1 (GND), TP33.1, TP37.1
unnamed: IC9.3 (OUT), TP42.1, TP44.1
unnamed: IC9.6 (THRES), TP20.1, TP21.1
unnamed: IC9.2 (TRIG), TP24.1, TP27.1
unnamed: IC9.8 (VCC), TP35.1, TP39.1
unnamed: IC9.4 (~RESET), TP26.1, TP28.1
unnamed: TP61.1, TP65.1, U4.4
unnamed: TP49.1, TP53.1, U4.3 (EN)
unnamed: TP58.1, TP62.1, U4.2 (G1)
unnamed: TP48.1, TP52.1, U4.1 (IN)
unnamed: TP60.1, TP64.1, U4.5 (OUT)

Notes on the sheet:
Testpoint e piazzole libere per esperimenti Free testpoints and pads for experiments

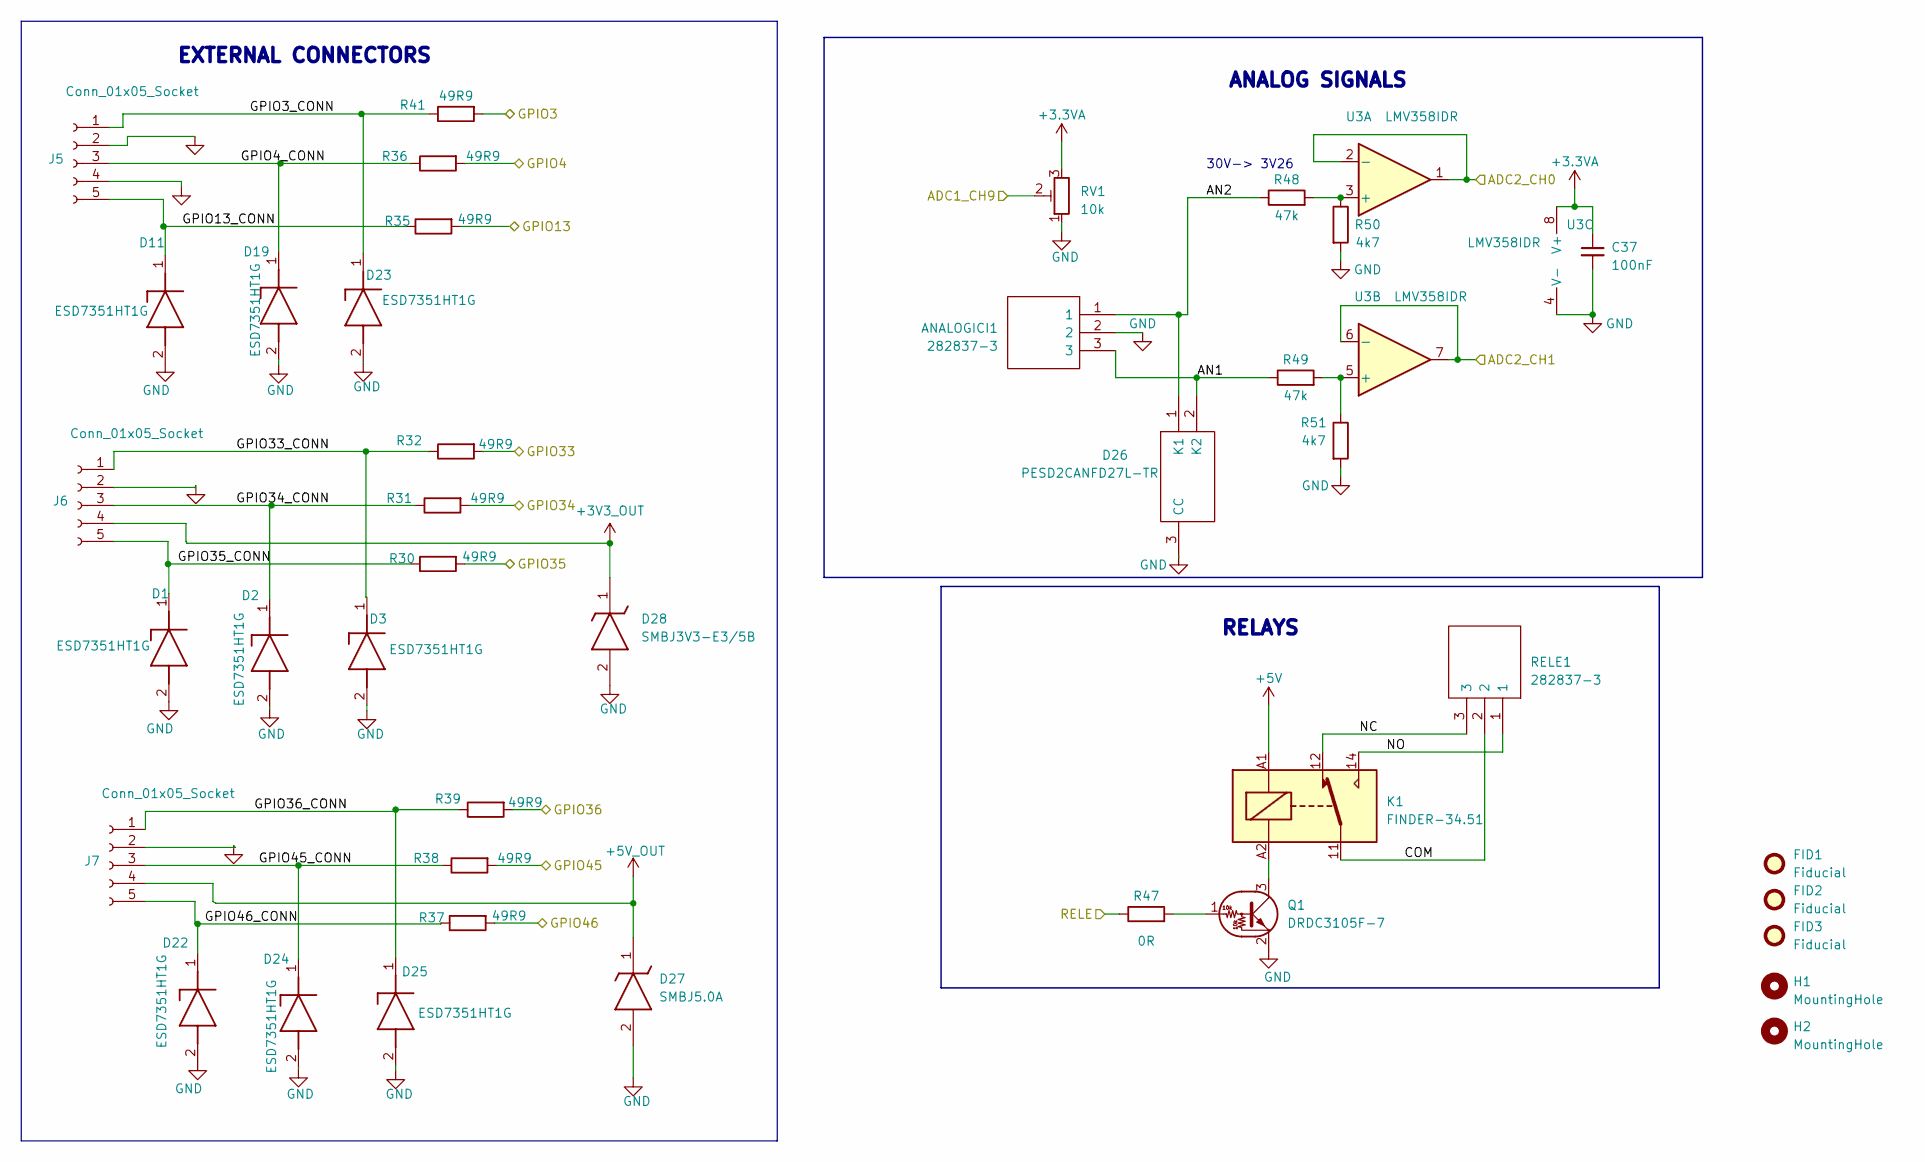
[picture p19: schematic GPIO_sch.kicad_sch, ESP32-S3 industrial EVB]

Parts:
ANALOGICI1: 282837-3; TerminalBlock_bornier-3_P5.08mm; Mouser Part Number 490-TB006-508-03BE
C37: 100nF; C_0603_1608Metric_Pad1.08x0.95mm_HandSolder
D1, D2, D3, D11, D19, D22, D23, D24, D25: ESD7351HT1G; SOD-323; Mouser Part Number 771-PESD3V3U1UB-T/R
D26: PESD2CANFD27L-TR; SOT-23-3; Mouser Part Number 771-PESD2CANFD24L-UX
D27: SMBJ5.0A; DIOM5436X244N; Mouser Part Number 78-SMBJ5.0A
D28: SMBJ3V3-E3/5B; DIOM5436X244N; Mouser Part Number 78-SMBJ5.0A
FID1, FID2, FID3: Fiducial; Fiducial_1.5mm_Mask3mm
H1, H2: MountingHole; MountingHole_3.2mm_M3
J5, J6, J7: Conn_01x05_Socket; PinSocket_1x05_P2.54mm_Vertical
K1: FINDER-34.51; Relay_SPDT_Finder_34.51_Vertical
Q1: DRDC3105F-7; SOT-23-3
R30, R31, R32, R35, R36, R37, R38, R39, R41: 49R9; R_0805_2012Metric_Pad1.20x1.40mm_HandSolder
R47: 0R; R_0603_1608Metric_Pad0.98x0.95mm_HandSolder
R48, R49: 47k; R_0603_1608Metric_Pad0.98x0.95mm_HandSolder
R50, R51: 4k7; R_0603_1608Metric_Pad0.98x0.95mm_HandSolder
RELE1: 282837-3; TerminalBlock_bornier-3_P5.08mm; Mouser Part Number 490-TB006-508-03BE
RV1: 10k; Potentiometer_Bourns_3314G_Vertical
U3: LMV358IDR; SO-8_3.9x4.9mm_P1.27mm

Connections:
+3.3VA: C37.1, RV1.3, U3.8 (V+); also elsewhere on the board
+3V3_OUT: D28.1 (K), J6.4; also elsewhere on the board
+5V: K1.A1; also elsewhere on the board
+5V_OUT: D27.1 (K), J7.4; also elsewhere on the board
/gerarchico Sheet/ESP32-S3 MCU/ADC1_CH9: RV1.2; also elsewhere on the board
/gerarchico Sheet/ESP32-S3 MCU/ADC2_CH0: U3.1, U3.2 (-); also elsewhere on the board
/gerarchico Sheet/ESP32-S3 MCU/ADC2_CH1: U3.6 (-), U3.7; also elsewhere on the board
/gerarchico Sheet/ESP32-S3 MCU/GPIO3: R41.2; also elsewhere on the board
/gerarchico Sheet/ESP32-S3 MCU/GPIO4: R36.2; also elsewhere on the board
/gerarchico Sheet/ESP32-S3 MCU/GPIO13: R35.2; also elsewhere on the board
/gerarchico Sheet/ESP32-S3 MCU/GPIO33: R32.2; also elsewhere on the board
/gerarchico Sheet/ESP32-S3 MCU/GPIO34: R31.2; also elsewhere on the board
/gerarchico Sheet/ESP32-S3 MCU/GPIO35: R30.2; also elsewhere on the board
/gerarchico Sheet/ESP32-S3 MCU/GPIO36: R39.2; also elsewhere on the board
/gerarchico Sheet/ESP32-S3 MCU/GPIO45: R38.2; also elsewhere on the board
/gerarchico Sheet/ESP32-S3 MCU/GPIO46: R37.2; also elsewhere on the board
/gerarchico Sheet/ESP32-S3 MCU/RELE: R47.1; also elsewhere on the board
/gerarchico Sheet/GPIO/AN1: ANALOGICI1.3, D26.2 (K2), R49.1
/gerarchico Sheet/GPIO/AN2: ANALOGICI1.1, D26.1 (K1), R48.1
/gerarchico Sheet/GPIO/COM: K1.11, RELE1.2
/gerarchico Sheet/GPIO/GPIO3_CONN: D23.1 (K), J5.1, R41.1
/gerarchico Sheet/GPIO/GPIO4_CONN: D19.1 (K), J5.3, R36.1
/gerarchico Sheet/GPIO/GPIO13_CONN: D11.1 (K), J5.5, R35.1
/gerarchico Sheet/GPIO/GPIO33_CONN: D3.1 (K), J6.1, R32.1
/gerarchico Sheet/GPIO/GPIO34_CONN: D2.1 (K), J6.3, R31.1
/gerarchico Sheet/GPIO/GPIO35_CONN: D1.1 (K), J6.5, R30.1
/gerarchico Sheet/GPIO/GPIO36_CONN: D25.1 (K), J7.1, R39.1
/gerarchico Sheet/GPIO/GPIO45_CONN: D24.1 (K), J7.3, R38.1
/gerarchico Sheet/GPIO/GPIO46_CONN: D22.1 (K), J7.5, R37.1
/gerarchico Sheet/GPIO/NC: K1.12, RELE1.3
/gerarchico Sheet/GPIO/NO: K1.14, RELE1.1
GND: ANALOGICI1.2, C37.2, D1.2 (A), D2.2 (A), D3.2 (A), D11.2 (A), D19.2 (A), D22.2 (A), D23.2 (A), D24.2 (A), D25.2 (A), D26.3 (CC), D27.2 (A), D28.2 (A), J5.2, J5.4, J6.2, J7.2, Q1.2 (E), R50.2, R51.2, RV1.1, U3.4 (V-); also elsewhere on the board
unnamed: Q1.1 (B), R47.2
unnamed: K1.A2, Q1.3 (C)
unnamed: R48.2, R50.1, U3.3 (+)
unnamed: R49.2, R51.1, U3.5 (+)

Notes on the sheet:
30V-> 3V26
ANALOG SIGNALS
RELAYS
EXTERNAL CONNECTORS

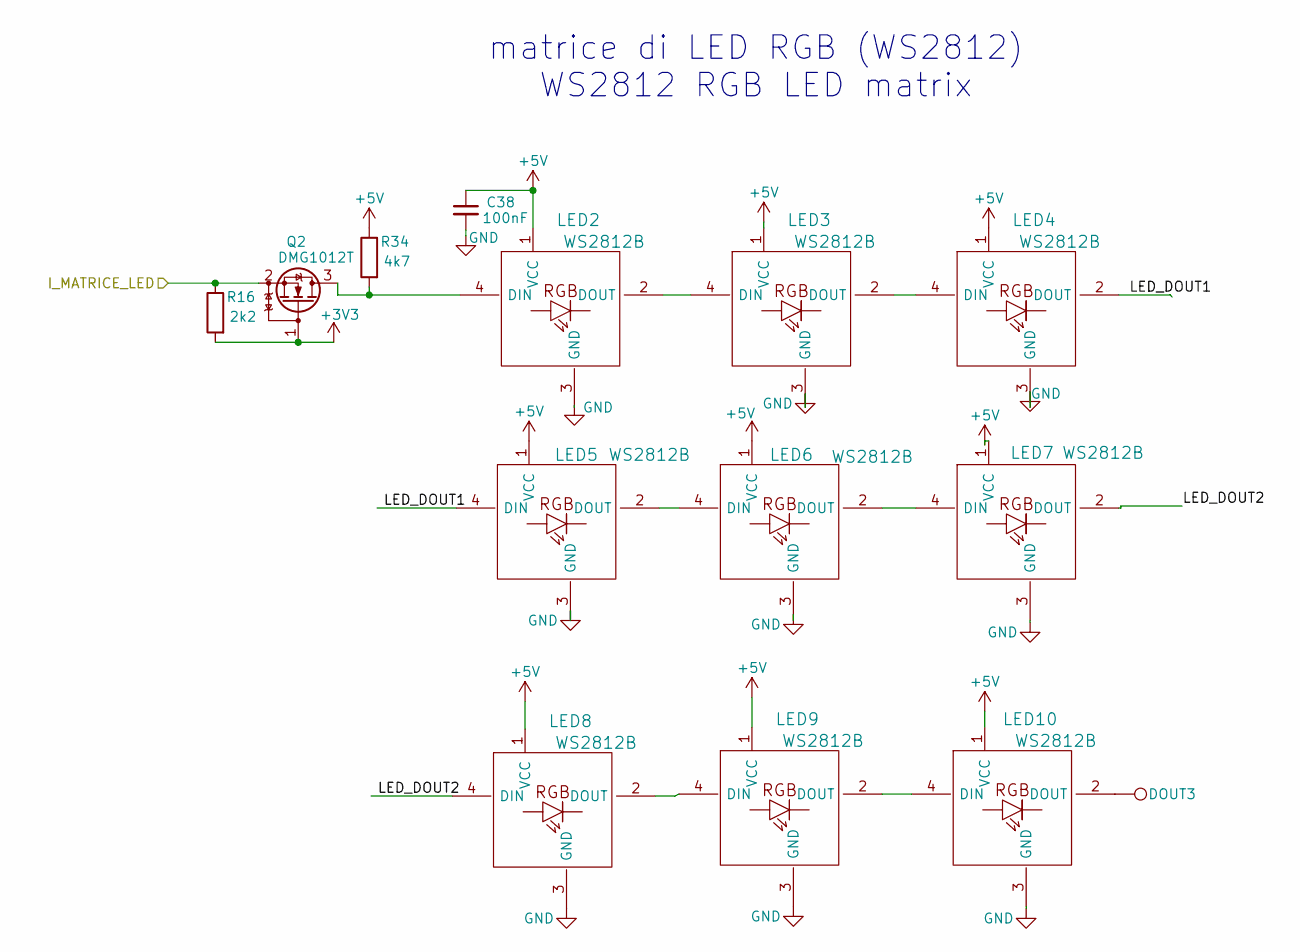
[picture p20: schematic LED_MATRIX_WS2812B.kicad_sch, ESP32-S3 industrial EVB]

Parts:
C38: 100nF; C_0603_1608Metric_Pad1.08x0.95mm_HandSolder
DOUT3: TestPoint; TestPoint_THTPad_D1.0mm_Drill0.5mm
LED2, LED3, LED4, LED5, LED6, LED7, LED8, LED9, LED10: WS2812B
Q2: DMG1012T; SOT-523
R16: 2k2; R_0603_1608Metric_Pad0.98x0.95mm_HandSolder
R34: 4k7; R_0603_1608Metric_Pad0.98x0.95mm_HandSolder

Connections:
+3V3: Q2.1 (G), R16.2; also elsewhere on the board
+5V: C38.1, LED2.1 (VCC), LED3.1 (VCC), LED4.1 (VCC), LED5.1 (VCC), LED6.1 (VCC), LED7.1 (VCC), LED8.1 (VCC), LED9.1 (VCC), LED10.1 (VCC), R34.1; also elsewhere on the board
/gerarchico Sheet/ESP32-S3 MCU/I_MATRICE_LED: Q2.2 (S), R16.1; also elsewhere on the board
/gerarchico Sheet/LED_MATRIX_WS2812B/LED_DOUT1: LED4.2 (DOUT), LED5.4 (DIN)
/gerarchico Sheet/LED_MATRIX_WS2812B/LED_DOUT2: LED7.2 (DOUT), LED8.4 (DIN)
GND: C38.2, LED2.3 (GND), LED3.3 (GND), LED4.3 (GND), LED5.3 (GND), LED6.3 (GND), LED7.3 (GND), LED8.3 (GND), LED9.3 (GND), LED10.3 (GND); also elsewhere on the board
unnamed: LED2.4 (DIN), Q2.3 (D), R34.2
unnamed: LED2.2 (DOUT), LED3.4 (DIN)
unnamed: LED3.2 (DOUT), LED4.4 (DIN)
unnamed: LED5.2 (DOUT), LED6.4 (DIN)
unnamed: LED6.2 (DOUT), LED7.4 (DIN)
unnamed: LED8.2 (DOUT), LED9.4 (DIN)
unnamed: LED9.2 (DOUT), LED10.4 (DIN)
unnamed: DOUT3.1, LED10.2 (DOUT)

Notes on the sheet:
matrice di LED RGB (WS2812) WS2812 RGB LED matrix

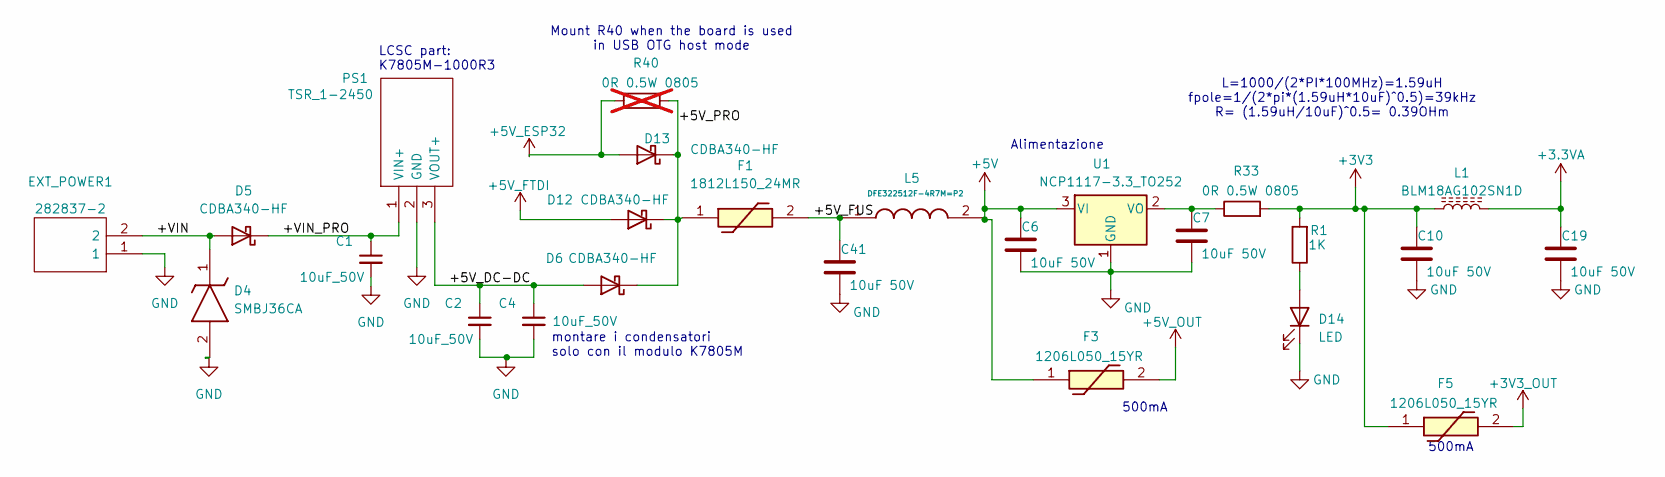
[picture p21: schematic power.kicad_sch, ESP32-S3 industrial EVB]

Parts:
C1, C2, C4: 10uF_50V; C_1206_3216Metric_Pad1.33x1.80mm_HandSolder
C6, C7, C10, C19, C41: 10uF 50V; C_1206_3216Metric_Pad1.33x1.80mm_HandSolder
D4: SMBJ36CA; DIOM5436X261N; Mouser Part Number SMBJ36CA
D5, D6, D12, D13: CDBA340-HF; SMA
D14: LED; LED_0603_1608Metric_Pad1.05x0.95mm_HandSolder
EXT_POWER1: 282837-2; 2828372; Mouser Part Number 571-2828372
F1: 1812L150_24MR; 1812L010DR; Mouser Part Number 576-1812L150/24MR
F3, F5: 1206L050_15YR; 1206L05015YR; Mouser Part Number 576-1206L050/15YR
L1: BLM18AG102SN1D; L_0603_1608Metric_Pad1.05x0.95mm_HandSolder
L5: DFE322512F-4R7M=P2; 1277ASH100MP2; Mouser Part Number 81-DFE322512F-4R7MP2
PS1: TSR_1-2450; Converter_DCDC_TRACO_TSR-1_THT; Mouser Part Number 495-TSR-1-2450
R1: 1K; R_0603_1608Metric_Pad0.98x0.95mm_HandSolder
R33: 0R 0.5W 0805; R_0805_2012Metric_Pad1.20x1.40mm_HandSolder
R40: 0R 0.5W 0805; R_0805_2012Metric_Pad1.20x1.40mm_HandSolder; not fitted
U1: NCP1117-3.3_TO252; TO-252-2

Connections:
+3.3VA: C19.1, L1.2; also elsewhere on the board
+3V3: C10.1, F5.1, L1.1, R1.2, R33.2; also elsewhere on the board
+3V3_OUT: F5.2; also elsewhere on the board
+5V: C6.1, F3.1, L5.2, U1.3 (VI); also elsewhere on the board
+5V_ESP32: D13.2 (A), R40.1; also elsewhere on the board
+5V_FTDI: D12.2 (A); also elsewhere on the board
+5V_OUT: F3.2; also elsewhere on the board
/gerarchico Sheet/Power/+5V_DC-DC: C2.1, C4.1, D6.2 (A), PS1.3 (VOUT+)
/gerarchico Sheet/Power/+5V_FUS: C41.1, F1.2, L5.1
/gerarchico Sheet/Power/+5V_PRO: D6.1 (K), D12.1 (K), D13.1 (K), F1.1, R40.2
/gerarchico Sheet/Power/+VIN: D4.1 (K), D5.2 (A), EXT_POWER1.2
/gerarchico Sheet/Power/+VIN_PRO: C1.1, D5.1 (K), PS1.1 (VIN+)
GND: C1.2, C2.2, C4.2, C6.2, C7.2, C10.2, C19.2, C41.2, D4.2 (A), D14.1 (K), EXT_POWER1.1, PS1.2 (GND), U1.1 (GND); also elsewhere on the board
unnamed: D14.2 (A), R1.1
unnamed: C7.1, R33.1, U1.2 (VO)

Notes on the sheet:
500mA
L=1000/(2*PI*100MHz)=1.59uH fpole=1/(2*pi*(1.59uH*10uF)^0.5)=39kHz R= (1.59uH/10uF)^0.5= 0.39OHm
LCSC part: K7805M-1000R3
Mount R40 when the board is used in USB OTG host mode
montare i condensatori solo con il modulo K7805M
Alimentazione

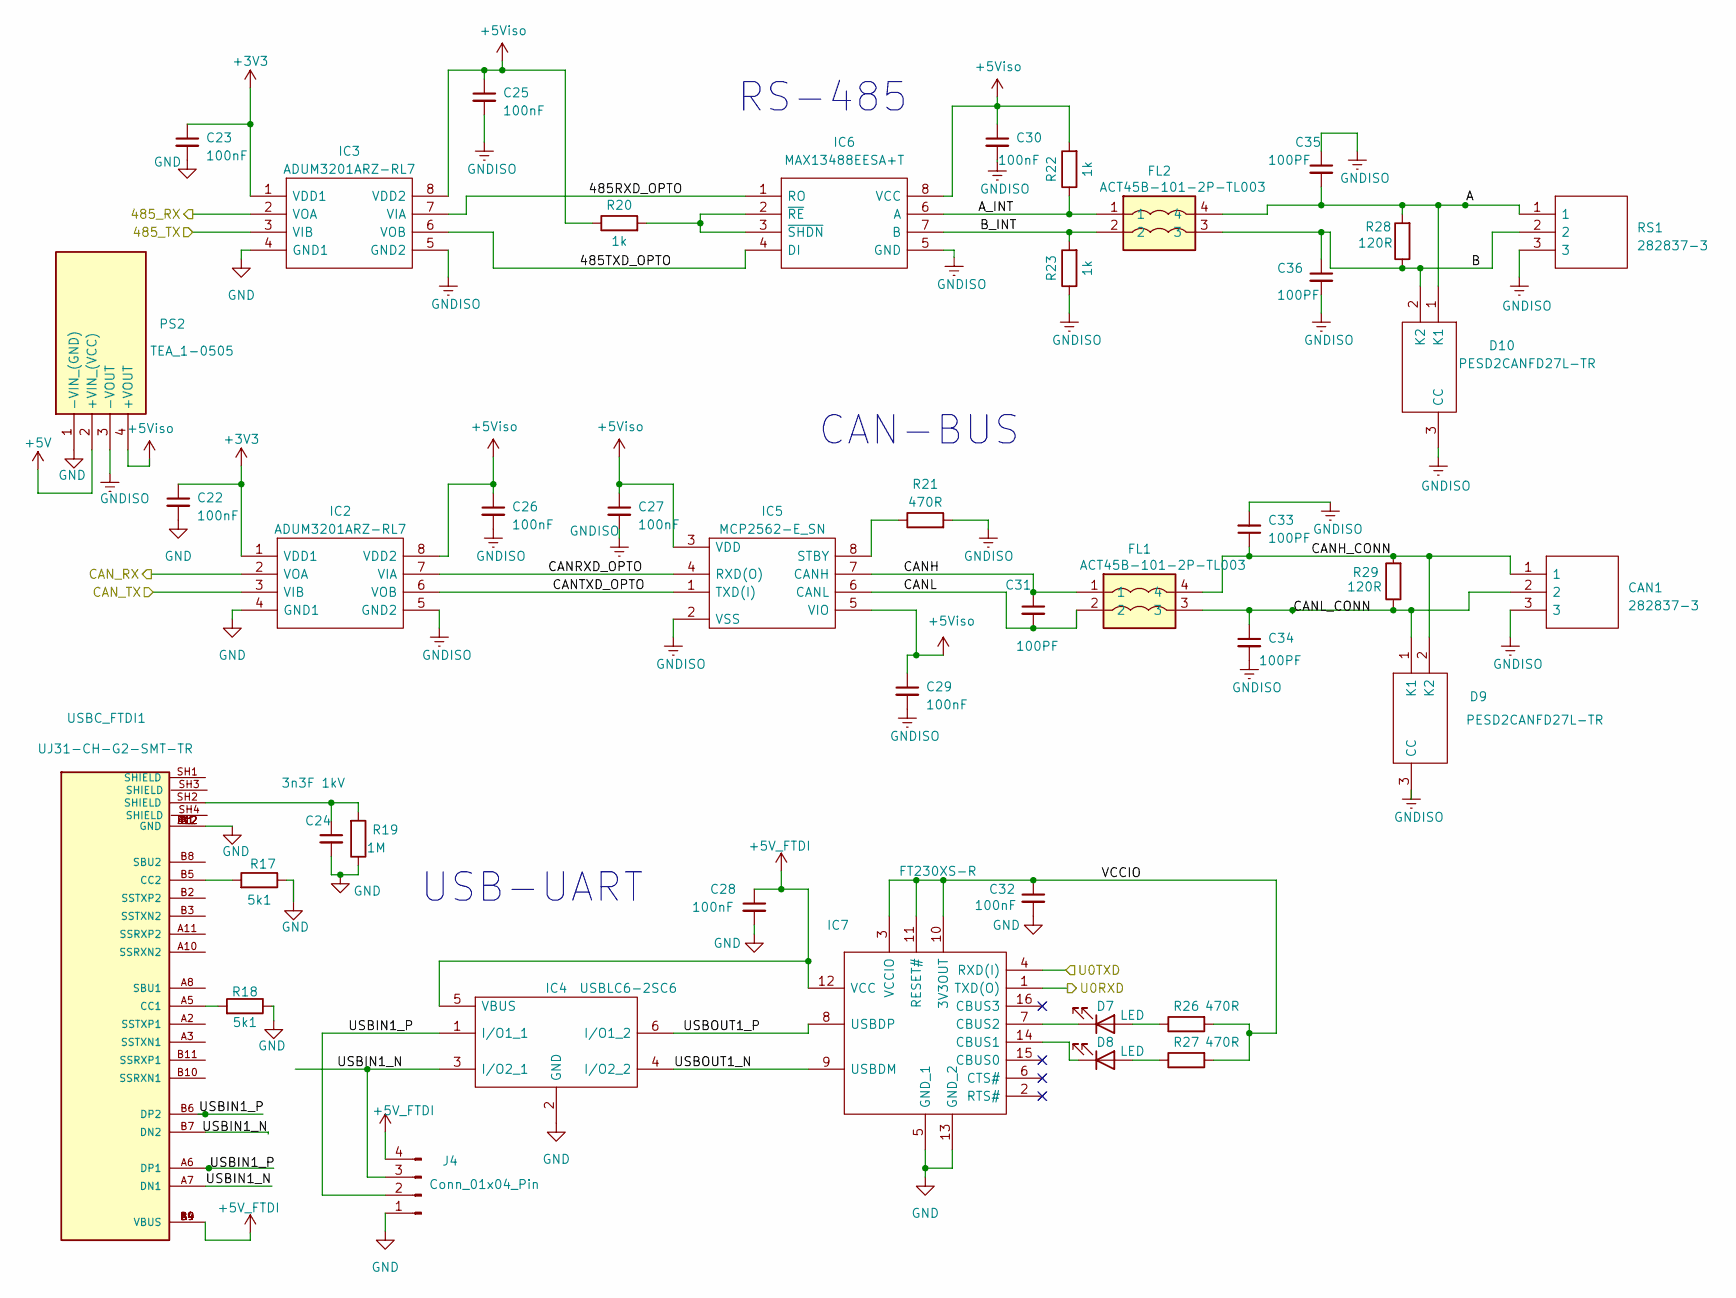
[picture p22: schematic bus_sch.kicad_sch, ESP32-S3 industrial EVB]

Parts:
C22, C23, C25, C26, C27, C28, C29, C30, C32: 100nF; C_0603_1608Metric_Pad1.08x0.95mm_HandSolder
C24: 3n3F 1kV; C_1206_3216Metric_Pad1.33x1.80mm_HandSolder
C31, C33, C34, C35, C36: 100PF; C_0603_1608Metric_Pad1.08x0.95mm_HandSolder
CAN1: 282837-3; TerminalBlock_bornier-3_P5.08mm; Mouser Part Number 490-TB006-508-03BE
D7, D8: LED; LED_0603_1608Metric_Pad1.05x0.95mm_HandSolder
D9, D10: PESD2CANFD27L-TR; SOT-23-3; Mouser Part Number 771-PESD2CANFD24L-UX
FL1, FL2: ACT45B-101-2P-TL003; ACT45B1012PTL003; Mouser Part Number 810-ACT1210D1012PTL0
IC2, IC3: ADUM3201ARZ-RL7; SO-8_3.9x4.9mm_P1.27mm; Mouser Part Number 584-ADUM3201ARZ-R7
IC4: USBLC6-2SC6; SOT23-6; Mouser Part Number 511-USBLC6-2SC6
IC5: MCP2562-E_SN; SO-8_3.9x4.9mm_P1.27mm; Mouser Part Number 579-MCP2562-E/SN
IC6: MAX13488EESA+T; SO-8_3.9x4.9mm_P1.27mm; Mouser Part Number 700-MAX13488EESAT
IC7: FT230XS-R; TSSOP-16_4.4x5mm_P0.65mm; Mouser Part Number 895-FT230XS-R
J4: Conn_01x04_Pin; PinHeader_1x04_P2.54mm_Vertical
PS2: TEA_1-0505; TEA10505; Mouser Part Number 495-TEA1-0505
R17, R18: 5k1; R_0603_1608Metric_Pad0.98x0.95mm_HandSolder
R19: 1M; R_0603_1608Metric_Pad0.98x0.95mm_HandSolder
R20, R22, R23: 1k; R_0603_1608Metric_Pad0.98x0.95mm_HandSolder
R21, R26, R27: 470R; R_0603_1608Metric_Pad0.98x0.95mm_HandSolder
R28, R29: 120R; R_0805_2012Metric_Pad1.20x1.40mm_HandSolder
RS1: 282837-3; TerminalBlock_bornier-3_P5.08mm; Mouser Part Number 490-TB006-508-03BE
USBC_FTDI1: UJ31-CH-G2-SMT-TR; UJ31CHG2SMTTR; PART_REV 1.01

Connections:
+3V3: C22.1, C23.1, IC2.1 (VDD1), IC3.1 (VDD1); also elsewhere on the board
+5V: PS2.2 (+VIN_(VCC)); also elsewhere on the board
+5V_FTDI: C28.1, IC4.5 (VBUS), IC7.12 (VCC), J4.4, USBC_FTDI1.A4 (VBUS), USBC_FTDI1.A9 (VBUS), USBC_FTDI1.B4 (VBUS), USBC_FTDI1.B9 (VBUS); also elsewhere on the board
+5Viso: C25.1, C26.1, C27.1, C29.1, C30.1, IC2.8 (VDD2), IC3.8 (VDD2), IC5.3 (VDD), IC5.5 (VIO), IC6.8 (VCC), PS2.4 (+VOUT), R20.1, R22.2
/gerarchico Sheet/ESP32-S3 MCU/485_RX: IC3.2 (VOA); also elsewhere on the board
/gerarchico Sheet/ESP32-S3 MCU/485_TX: IC3.3 (VIB); also elsewhere on the board
/gerarchico Sheet/ESP32-S3 MCU/CAN_RX: IC2.2 (VOA); also elsewhere on the board
/gerarchico Sheet/ESP32-S3 MCU/CAN_TX: IC2.3 (VIB); also elsewhere on the board
/gerarchico Sheet/ESP32-S3 MCU/U0RXD: IC7.1 (TXD(O)); also elsewhere on the board
/gerarchico Sheet/ESP32-S3 MCU/U0TXD: IC7.4 (RXD(I)); also elsewhere on the board
/gerarchico Sheet/bus/485RXD_OPTO: IC3.7 (VIA), IC6.1 (RO)
/gerarchico Sheet/bus/485TXD_OPTO: IC3.6 (VOB), IC6.4 (DI)
/gerarchico Sheet/bus/A: C35.2, D10.1 (K1), FL2.4, R28.2, RS1.1
/gerarchico Sheet/bus/A_INT: FL2.1, IC6.6 (A), R22.1
/gerarchico Sheet/bus/B: C36.1, D10.2 (K2), FL2.3, R28.1, RS1.2
/gerarchico Sheet/bus/B_INT: FL2.2, IC6.7 (B), R23.2
/gerarchico Sheet/bus/CANH: C31.1, FL1.1, IC5.7 (CANH)
/gerarchico Sheet/bus/CANH_CONN: C33.1, CAN1.1, D9.2 (K2), FL1.4, R29.2
/gerarchico Sheet/bus/CANL: C31.2, FL1.2, IC5.6 (CANL)
/gerarchico Sheet/bus/CANL_CONN: C34.1, CAN1.2, D9.1 (K1), FL1.3, R29.1
/gerarchico Sheet/bus/CANRXD_OPTO: IC2.7 (VIA), IC5.4 (RXD(O))
/gerarchico Sheet/bus/CANTXD_OPTO: IC2.6 (VOB), IC5.1 (TXD(I))
/gerarchico Sheet/bus/USBIN1_N: IC4.3 (I/O2_1), J4.3, USBC_FTDI1.A7 (DN1), USBC_FTDI1.B7 (DN2)
/gerarchico Sheet/bus/USBIN1_P: IC4.1 (I/O1_1), J4.2, USBC_FTDI1.A6 (DP1), USBC_FTDI1.B6 (DP2)
/gerarchico Sheet/bus/USBOUT1_N: IC4.4 (I/O2_2), IC7.9 (USBDM)
/gerarchico Sheet/bus/USBOUT1_P: IC4.6 (I/O1_2), IC7.8 (USBDP)
/gerarchico Sheet/bus/VCCIO: C32.1, IC7.3 (VCCIO), IC7.10 (3V3OUT), IC7.11 (RESET#), R26.2, R27.2
GND: C22.2, C23.2, C24.2, C28.2, C32.2, IC2.4 (GND1), IC3.4 (GND1), IC4.2 (GND), IC7.5 (GND_1), IC7.13 (GND_2), J4.1, PS2.1 (-VIN_(GND)), R17.1, R18.1, R19.1, USBC_FTDI1.A1 (GND), USBC_FTDI1.A12 (GND), USBC_FTDI1.B1 (GND), USBC_FTDI1.B12 (GND); also elsewhere on the board
GNDISO: C25.2, C26.2, C27.2, C29.2, C30.2, C33.2, C34.2, C35.1, C36.2, CAN1.3, D9.3 (CC), D10.3 (CC), IC2.5 (GND2), IC3.5 (GND2), IC5.2 (VSS), IC6.5 (GND), PS2.3 (-VOUT), R21.2, R23.1, RS1.3
unnamed: C24.1, R19.2, USBC_FTDI1.SH2 (SHIELD)
unnamed: D7.2 (A), R26.1
unnamed: D7.1 (K), IC7.7 (CBUS2)
unnamed: D8.2 (A), R27.1
unnamed: D8.1 (K), IC7.14 (CBUS1)
unnamed: IC5.8 (STBY), R21.1
unnamed: IC6.2 (~RE), IC6.3 (~SHDN), R20.2
unnamed: R18.2, USBC_FTDI1.A5 (CC1)
unnamed: R17.2, USBC_FTDI1.B5 (CC2)

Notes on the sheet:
USB-UART
CAN-BUS
RS-485

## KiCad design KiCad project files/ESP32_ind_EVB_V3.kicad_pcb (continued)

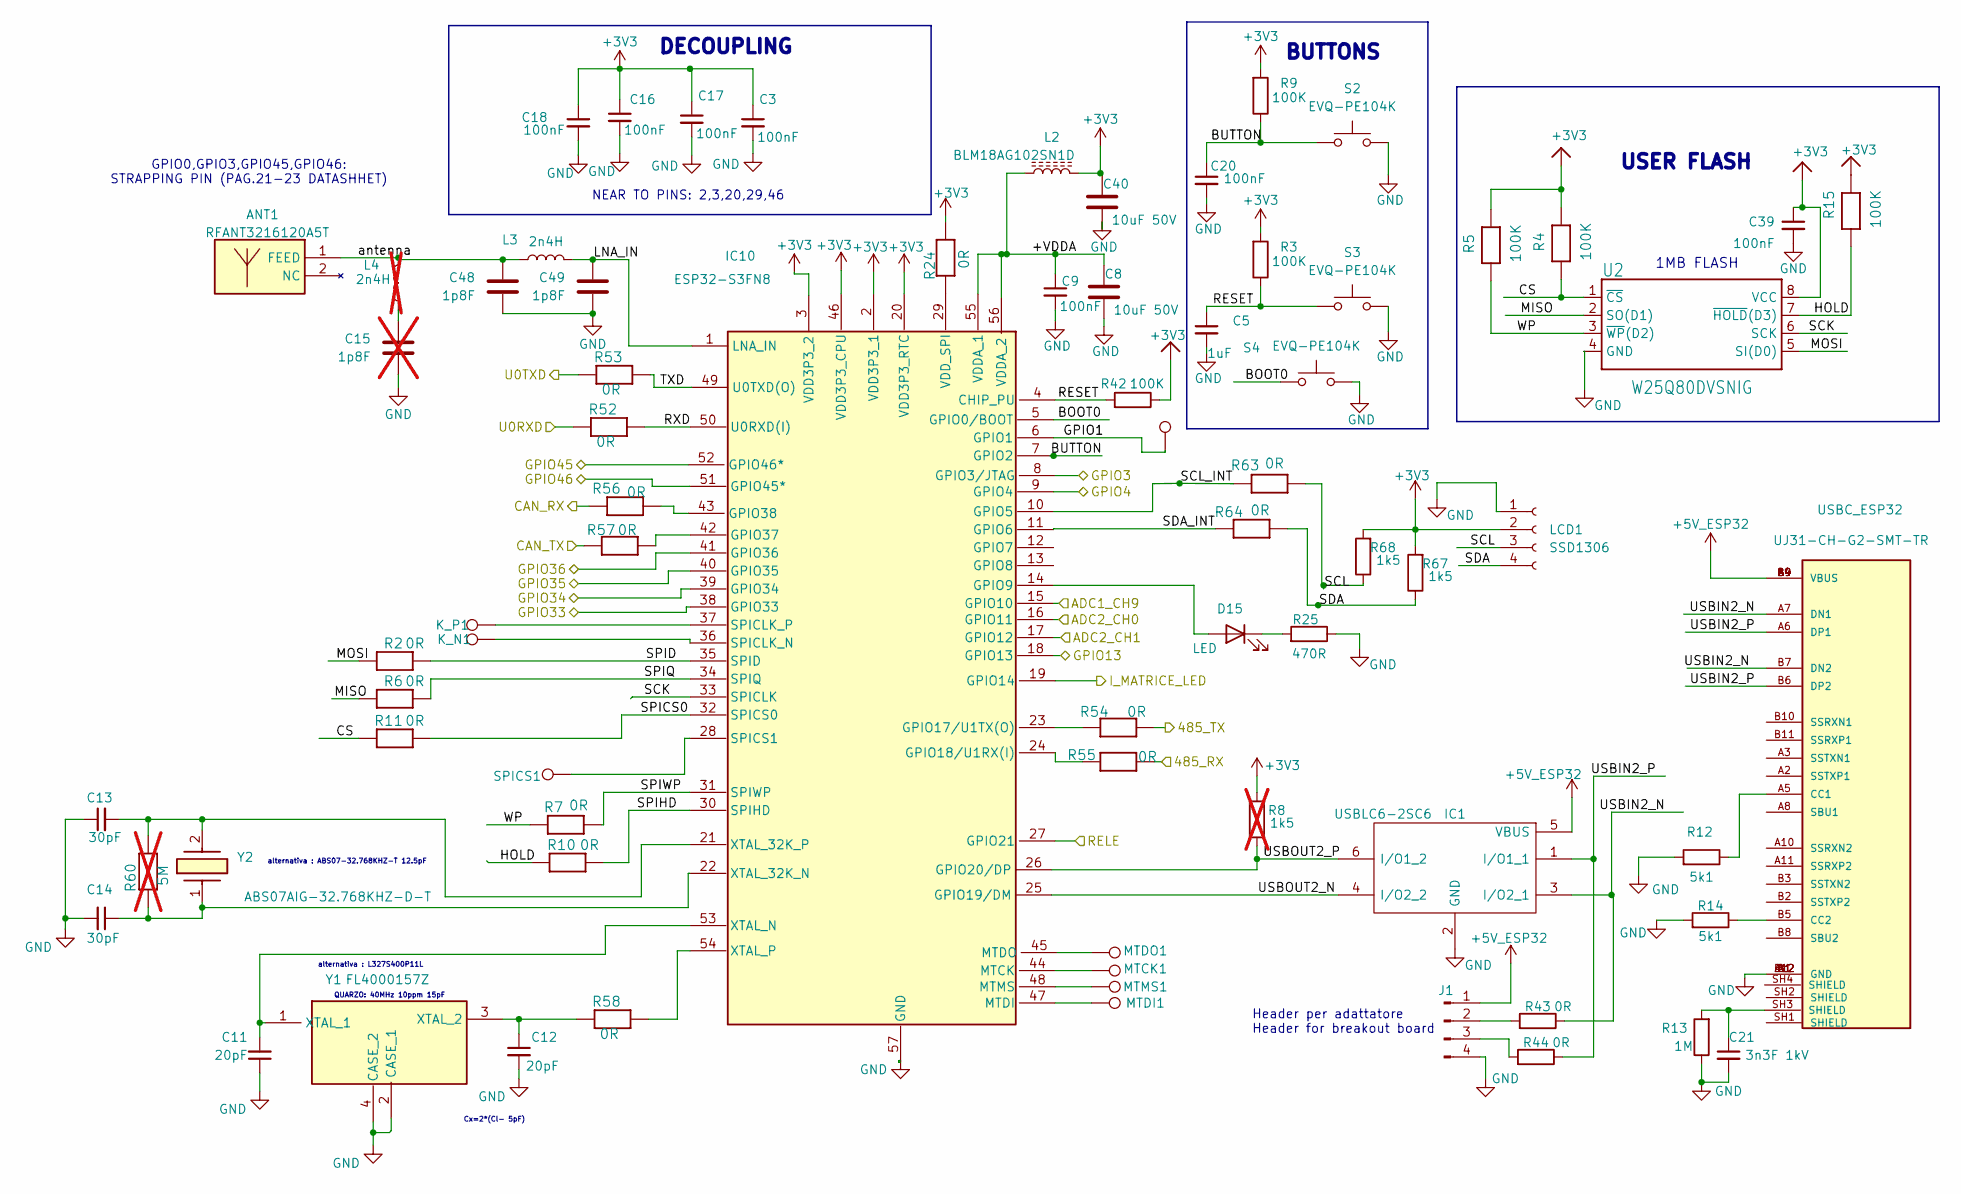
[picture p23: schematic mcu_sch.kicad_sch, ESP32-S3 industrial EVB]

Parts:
ANT1: RFANT3216120A5T; ANTC3216X130N; Mouser Part Number 791-RFANT3216120A5T
C3, C9, C16, C17, C18, C20, C39: 100nF; C_0603_1608Metric_Pad1.08x0.95mm_HandSolder
C5: 1uF; C_0603_1608Metric_Pad1.08x0.95mm_HandSolder
C8, C40: 10uF 50V; C_1206_3216Metric_Pad1.33x1.80mm_HandSolder
C11, C12: 20pF; C_0603_1608Metric_Pad1.08x0.95mm_HandSolder
C13, C14: 30pF; C_0603_1608Metric_Pad1.08x0.95mm_HandSolder
C15: 1p8F; C_0603_1608Metric_Pad1.08x0.95mm_HandSolder; not fitted
C21: 3n3F 1kV; C_1206_3216Metric_Pad1.33x1.80mm_HandSolder
C48, C49: 1p8F; C_0603_1608Metric_Pad1.08x0.95mm_HandSolder
D15: LED; LED_0603_1608Metric_Pad1.05x0.95mm_HandSolder
IC1: USBLC6-2SC6; SOT23-6; Mouser Part Number 511-USBLC6-2SC6
IC10: ESP32-S3FN8; QFN40P700X700X90-57N-D; Mouser Part Number 356-ESP32-S3FN8
J1: Conn_01x04_Pin; PinHeader_1x04_P2.54mm_Vertical
K_N1: TestPoint; TestPoint_THTPad_D1.0mm_Drill0.5mm
K_P1: TestPoint; TestPoint_THTPad_D1.0mm_Drill0.5mm
L2: BLM18AG102SN1D; L_0603_1608Metric_Pad1.05x0.95mm_HandSolder
L3: 2n4H; L_0603_1608Metric
L4: 2n4H; L_0603_1608Metric; not fitted
LCD1: SSD1306; PinHeader_1x04_P2.54mm_Vertical
MTCK1: TestPoint; TestPoint_THTPad_D1.0mm_Drill0.5mm
MTDI1: TestPoint; TestPoint_THTPad_D1.0mm_Drill0.5mm
MTDO1: TestPoint; TestPoint_THTPad_D1.0mm_Drill0.5mm
MTMS1: TestPoint; TestPoint_THTPad_D1.0mm_Drill0.5mm
R2, R6, R7, R10, R11, R24, R43, R44, R52, R53, R54, R55, R56, R57, R58, R63, R64: 0R; R_0603_1608Metric_Pad0.98x0.95mm_HandSolder
R3, R4, R5, R9, R15, R42: 100K; R_0603_1608Metric_Pad0.98x0.95mm_HandSolder
R8: 1k5; R_0603_1608Metric_Pad0.98x0.95mm_HandSolder; not fitted
R12, R14: 5k1; R_0603_1608Metric_Pad0.98x0.95mm_HandSolder
R13: 1M; R_0603_1608Metric_Pad0.98x0.95mm_HandSolder
R25: 470R; R_0603_1608Metric_Pad0.98x0.95mm_HandSolder
R60: 5M; R_0603_1608Metric_Pad0.98x0.95mm_HandSolder; not fitted
R67, R68: 1k5; R_0603_1608Metric_Pad0.98x0.95mm_HandSolder
S2, S3, S4: EVQ-PE104K; EVQPE104K; Mouser Part Number 667-EVQ-PE104K
SPICS1: TestPoint; TestPoint_THTPad_D1.0mm_Drill0.5mm
TP72: TestPoint; TestPoint_Pad_through hole 1.5mm
U2: W25Q80DVSNIG; SOIC-8_3.9x4.9mm_P1.27mm
USBC_ESP32: UJ31-CH-G2-SMT-TR; UJ31CHG2SMTTR; PART_REV 1.01
Y1: FL4000157Z; Mouser Part Number 729-FL4000157Z
Y2: ABS07AIG-32.768KHZ-D-T; ABS07AIG; Mouser Part Number 815-S07AIG-32.768-DT

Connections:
+3V3: C3.1, C16.1, C17.1, C18.1, C39.1, C40.1, IC10.2 (VDD3P3_1), IC10.3 (VDD3P3_2), IC10.20 (VDD3P3_RTC), IC10.46 (VDD3P3_CPU), L2.2, LCD1.2, R3.2, R4.2, R5.2, R8.2, R9.2, R15.2, R24.1, R42.1, R67.2, R68.2, U2.8 (VCC); also elsewhere on the board
+5V_ESP32: IC1.5 (VBUS), J1.1, USBC_ESP32.A4 (VBUS), USBC_ESP32.A9 (VBUS), USBC_ESP32.B4 (VBUS), USBC_ESP32.B9 (VBUS); also elsewhere on the board
/gerarchico Sheet/ESP32-S3 MCU/485_RX: R55.1; also elsewhere on the board
/gerarchico Sheet/ESP32-S3 MCU/485_TX: R54.1; also elsewhere on the board
/gerarchico Sheet/ESP32-S3 MCU/+VDDA: C8.1, C9.1, IC10.55 (VDDA_1), IC10.56 (VDDA_2), L2.1
/gerarchico Sheet/ESP32-S3 MCU/ADC1_CH9: IC10.15 (GPIO10); also elsewhere on the board
/gerarchico Sheet/ESP32-S3 MCU/ADC2_CH0: IC10.16 (GPIO11); also elsewhere on the board
/gerarchico Sheet/ESP32-S3 MCU/ADC2_CH1: IC10.17 (GPIO12); also elsewhere on the board
/gerarchico Sheet/ESP32-S3 MCU/BOOT0: IC10.5 (GPIO0/BOOT), S4.1
/gerarchico Sheet/ESP32-S3 MCU/BUTTON: C20.1, IC10.7 (GPIO2), R9.1, S2.1
/gerarchico Sheet/ESP32-S3 MCU/CAN_RX: R56.2; also elsewhere on the board
/gerarchico Sheet/ESP32-S3 MCU/CAN_TX: R57.2; also elsewhere on the board
/gerarchico Sheet/ESP32-S3 MCU/CS: R4.1, R11.2, U2.1 (~CS)
/gerarchico Sheet/ESP32-S3 MCU/GPIO1: IC10.6 (GPIO1), TP72.1
/gerarchico Sheet/ESP32-S3 MCU/GPIO3: IC10.8 (GPIO3/JTAG); also elsewhere on the board
/gerarchico Sheet/ESP32-S3 MCU/GPIO4: IC10.9 (GPIO4); also elsewhere on the board
/gerarchico Sheet/ESP32-S3 MCU/GPIO13: IC10.18 (GPIO13); also elsewhere on the board
/gerarchico Sheet/ESP32-S3 MCU/GPIO33: IC10.38 (GPIO33); also elsewhere on the board
/gerarchico Sheet/ESP32-S3 MCU/GPIO34: IC10.39 (GPIO34); also elsewhere on the board
/gerarchico Sheet/ESP32-S3 MCU/GPIO35: IC10.40 (GPIO35); also elsewhere on the board
/gerarchico Sheet/ESP32-S3 MCU/GPIO36: IC10.41 (GPIO36); also elsewhere on the board
/gerarchico Sheet/ESP32-S3 MCU/GPIO45: IC10.52 (GPIO46*); also elsewhere on the board
/gerarchico Sheet/ESP32-S3 MCU/GPIO46: IC10.51 (GPIO45*); also elsewhere on the board
/gerarchico Sheet/ESP32-S3 MCU/HOLD: R10.2, R15.1, U2.7 (~HOLD(D3))
/gerarchico Sheet/ESP32-S3 MCU/I_MATRICE_LED: IC10.19 (GPIO14); also elsewhere on the board
/gerarchico Sheet/ESP32-S3 MCU/LNA_IN: C49.1, IC10.1 (LNA_IN), L3.1
/gerarchico Sheet/ESP32-S3 MCU/MISO: R6.2, U2.2 (SO(D1))
/gerarchico Sheet/ESP32-S3 MCU/MOSI: R2.2, U2.5 (SI(D0))
/gerarchico Sheet/ESP32-S3 MCU/RELE: IC10.27 (GPIO21); also elsewhere on the board
/gerarchico Sheet/ESP32-S3 MCU/RESET: C5.1, IC10.4 (CHIP_PU), R3.1, R42.2, S3.1
/gerarchico Sheet/ESP32-S3 MCU/RXD: IC10.50 (U0RXD(I)), R52.1
/gerarchico Sheet/ESP32-S3 MCU/SCK: IC10.33 (SPICLK), U2.6 (SCK)
/gerarchico Sheet/ESP32-S3 MCU/SCL: LCD1.3, R63.2, R68.1
/gerarchico Sheet/ESP32-S3 MCU/SCL_INT: IC10.10 (GPIO5), R63.1
/gerarchico Sheet/ESP32-S3 MCU/SDA: LCD1.4, R64.2, R67.1
/gerarchico Sheet/ESP32-S3 MCU/SDA_INT: IC10.11 (GPIO6), R64.1
/gerarchico Sheet/ESP32-S3 MCU/SPICS0: IC10.32 (SPICS0), R11.1
/gerarchico Sheet/ESP32-S3 MCU/SPID: IC10.35 (SPID), R2.1
/gerarchico Sheet/ESP32-S3 MCU/SPIHD: IC10.30 (SPIHD), R10.1
/gerarchico Sheet/ESP32-S3 MCU/SPIQ: IC10.34 (SPIQ), R6.1
/gerarchico Sheet/ESP32-S3 MCU/SPIWP: IC10.31 (SPIWP), R7.1
/gerarchico Sheet/ESP32-S3 MCU/TXD: IC10.49 (U0TXD(O)), R53.1
/gerarchico Sheet/ESP32-S3 MCU/U0RXD: R52.2; also elsewhere on the board
/gerarchico Sheet/ESP32-S3 MCU/U0TXD: R53.2; also elsewhere on the board
/gerarchico Sheet/ESP32-S3 MCU/USBIN2_N: IC1.3 (I/O2_1), R43.1, USBC_ESP32.A7 (DN1), USBC_ESP32.B7 (DN2)
/gerarchico Sheet/ESP32-S3 MCU/USBIN2_P: IC1.1 (I/O1_1), R44.1, USBC_ESP32.A6 (DP1), USBC_ESP32.B6 (DP2)
/gerarchico Sheet/ESP32-S3 MCU/USBOUT2_N: IC1.4 (I/O2_2), IC10.25 (GPIO19/DM)
/gerarchico Sheet/ESP32-S3 MCU/USBOUT2_P: IC1.6 (I/O1_2), IC10.26 (GPIO20/DP), R8.1
/gerarchico Sheet/ESP32-S3 MCU/WP: R5.1, R7.2, U2.3 (~WP(D2))
/gerarchico Sheet/ESP32-S3 MCU/antenna: ANT1.1 (FEED), C48.1, L3.2, L4.1
GND: C3.2, C5.2, C8.2, C9.2, C11.1, C12.2, C13.1, C14.2, C15.2, C16.2, C17.2, C18.2, C20.2, C21.2, C39.2, C40.2, C48.2, C49.2, IC1.2 (GND), IC10.57 (GND), J1.4, LCD1.1, R12.2, R13.1, R14.2, R25.1, S2.2, S3.2, S4.2, U2.4 (GND), USBC_ESP32.A1 (GND), USBC_ESP32.A12 (GND), USBC_ESP32.B1 (GND), USBC_ESP32.B12 (GND), Y1.2 (CASE_1), Y1.4 (CASE_2); also elsewhere on the board
unnamed: C15.1, L4.2
unnamed: C21.1, R13.2, USBC_ESP32.SH3 (SHIELD)
unnamed: D15.2 (A), IC10.14 (GPIO9)
unnamed: D15.1 (K), R25.2
unnamed: IC10.23 (GPIO17/U1TX(O)), R54.2
unnamed: IC10.24 (GPIO18/U1RX(I)), R55.2
unnamed: IC10.42 (GPIO37), R57.1
unnamed: IC10.43 (GPIO38), R56.1
unnamed: IC10.44 (MTCK), MTCK1.1
unnamed: IC10.47 (MTDI), MTDI1.1
unnamed: IC10.45 (MTDO), MTDO1.1
unnamed: IC10.48 (MTMS), MTMS1.1
unnamed: IC10.36 (SPICLK_N), K_N1.1
unnamed: IC10.37 (SPICLK_P), K_P1.1
unnamed: IC10.28 (SPICS1), SPICS1.1
unnamed: IC10.29 (VDD_SPI), R24.2
unnamed: C14.1, IC10.22 (XTAL_32K_N), R60.2, Y2.1
unnamed: C13.2, IC10.21 (XTAL_32K_P), R60.1, Y2.2
unnamed: C11.2, IC10.53 (XTAL_N), Y1.1 (XTAL_1)
unnamed: IC10.54 (XTAL_P), R58.1
unnamed: J1.2, R43.2
unnamed: J1.3, R44.2
unnamed: R12.1, USBC_ESP32.A5 (CC1)
unnamed: R14.1, USBC_ESP32.B5 (CC2)
unnamed: C12.1, R58.2, Y1.3 (XTAL_2)

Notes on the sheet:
USER FLASH
GPIO0,GPIO3,GPIO45,GPIO46: STRAPPING PIN (PAG.21-23 DATASHHET)
1MB FLASH
NEAR TO PINS: 2,3,20,29,46
BUTTONS
Header per adattatore Header for breakout board
QUARZO: 40MHz 10ppm 15pF
alternativa : L327S400P11L
Cx=2*(Cl- 5pF)
alternativa : ABS07-32.768KHZ-T 12.5pF
DECOUPLING

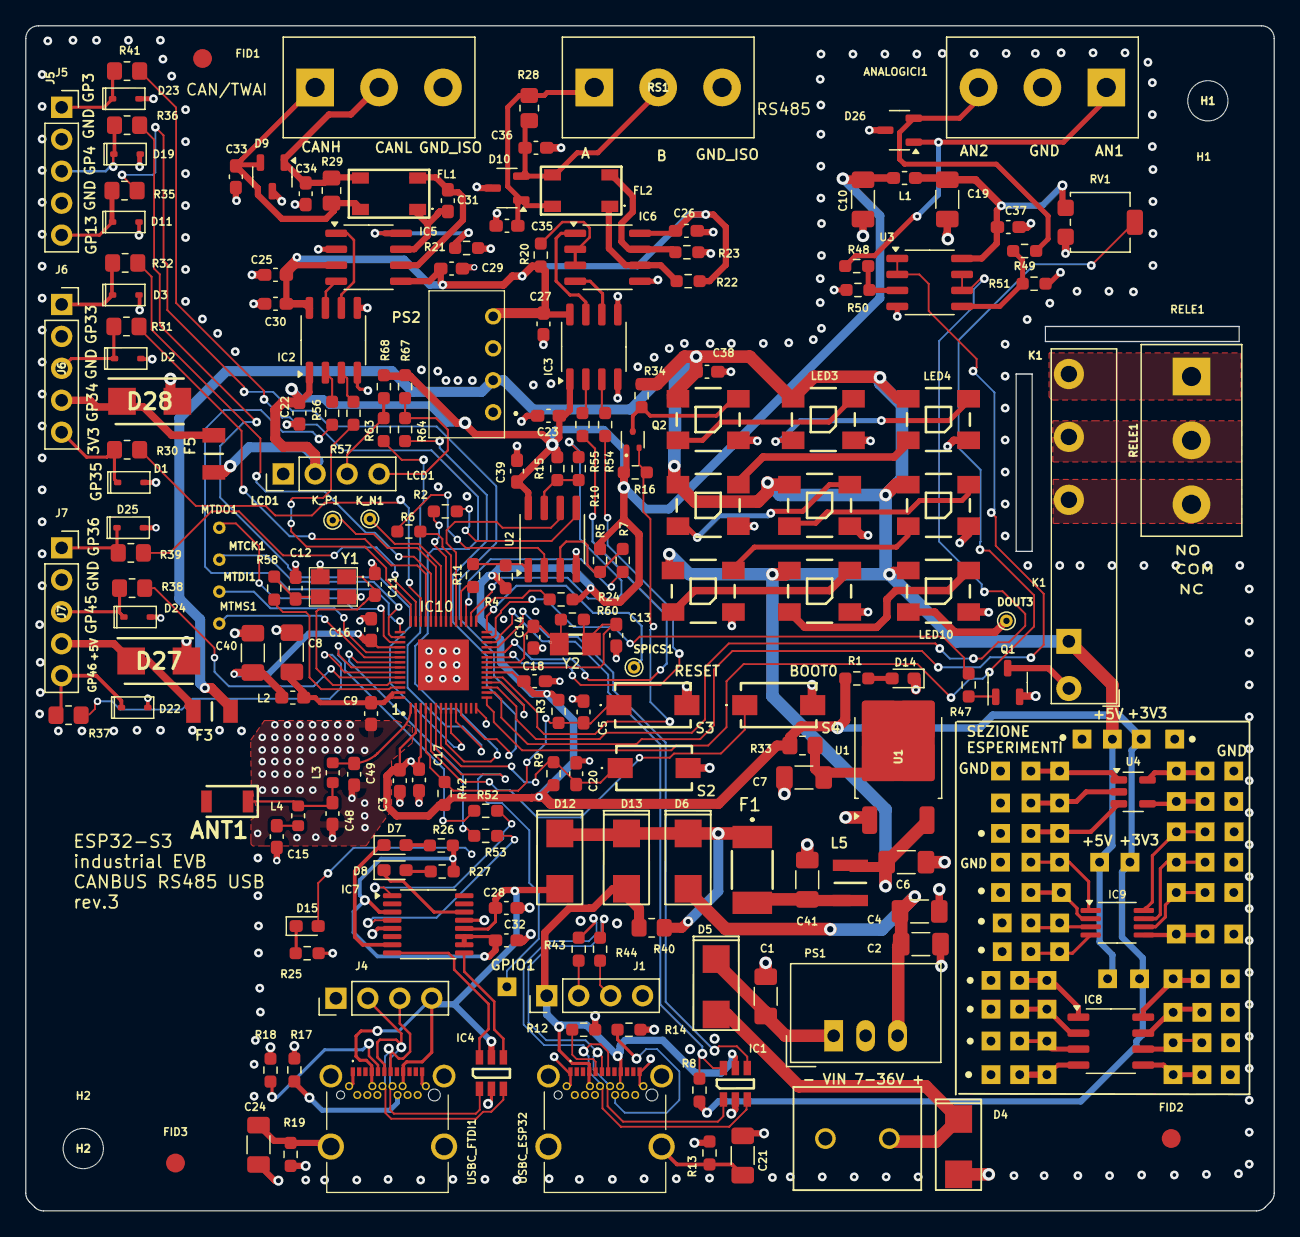
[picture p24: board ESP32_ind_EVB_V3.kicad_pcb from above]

Board: 4 copper layers, 99.2 x 94.2 mm, 270 parts (0 on the bottom side), 165 nets.

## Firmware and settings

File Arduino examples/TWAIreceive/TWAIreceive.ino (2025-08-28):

/* ESP32 TWAI receive example.
  Receive messages and sends them over serial.

  Connect a CAN bus transceiver to the RX/TX pins.
  For example: SN65HVD230

  TWAI_MODE_LISTEN_ONLY is used so that the TWAI controller will not influence the bus.

  The API gives other possible speeds and alerts:
  https://docs.espressif.com/projects/esp-idf/en/latest/esp32/api-reference/peripherals/twai.html

  Example output from a can bus message:
  -> Message received
  -> Message is in Standard Format
  -> ID: 604
  -> Byte: 0 = 00, 1 = 0f, 2 = 13, 3 = 02, 4 = 00, 5 = 00, 6 = 08, 7 = 00

  Example output with alerts:
  -> Alert: A (Bit, Stuff, CRC, Form, ACK) error has occurred on the bus.
  -> Bus error count: 171
  -> Alert: The RX queue is full causing a received frame to be lost.
  -> RX buffered: 4  RX missed: 46 RX overrun 0

  created 05-11-2022 by Stephan Martin (designer2k2)
*/

#pragma GCC diagnostic ignored "-Wmissing-field-initializers"
#include "driver/twai.h"

// Pins used to connect to CAN bus transceiver:
#define RX_PIN 38
#define TX_PIN 37

// Interval:
#define POLLING_RATE_MS 1000

static bool driver_installed = false;

void setup() {
  // Start Serial:
  Serial.begin(115200);

  // Initialize configuration structures using macro initializers
  twai_general_config_t g_config = TWAI_GENERAL_CONFIG_DEFAULT((gpio_num_t)TX_PIN, (gpio_num_t)RX_PIN, TWAI_MODE_LISTEN_ONLY);
  twai_timing_config_t t_config = TWAI_TIMING_CONFIG_500KBITS();  //Look in the api-reference for other speed sets.
  twai_filter_config_t f_config = TWAI_FILTER_CONFIG_ACCEPT_ALL();

  // Install TWAI driver
  if (twai_driver_install(&g_config, &t_config, &f_config) == ESP_OK) {
    Serial.println("Driver installed");
  } else {
    Serial.println("Failed to install driver");
    return;
  }

  // Start TWAI driver
  if (twai_start() == ESP_OK) {
    Serial.println("Driver started");
  } else {
    Serial.println("Failed to start driver");
    return;
  }

  // Reconfigure alerts to detect frame receive, Bus-Off error and RX queue full states
  uint32_t alerts_to_enable = TWAI_ALERT_RX_DATA | TWAI_ALERT_ERR_PASS | TWAI_ALERT_BUS_ERROR | TWAI_ALERT_RX_QUEUE_FULL;
  if (twai_reconfigure_alerts(alerts_to_enable, NULL) == ESP_OK) {
    Serial.println("CAN Alerts reconfigured");
  } else {
    Serial.println("Failed to reconfigure alerts");
    return;
  }

  // TWAI driver is now successfully installed and started
  driver_installed = true;
}

static void handle_rx_message(twai_message_t &message) {
  // Process received message
  if (message.extd) {
    Serial.println("Message is in Extended Format");
  } else {
    Serial.println("Message is in Standard Format");
  }
  Serial.printf("ID: %lx\nByte:", message.identifier);
  if (!(message.rtr)) {
    for (int i = 0; i < message.data_length_code; i++) {
      Serial.printf(" %d = %02x,", i, message.data[i]);
    }
    Serial.println("");
  }
}

void loop() {
  if (!driver_installed) {
    // Driver not installed
    delay(1000);
    return;
  }
  // Check if alert happened
  uint32_t alerts_triggered;
  twai_read_alerts(&alerts_triggered, pdMS_TO_TICKS(POLLING_RATE_MS));
  twai_status_info_t twaistatus;
  twai_get_status_info(&twaistatus);

  // Handle alerts
  if (alerts_triggered & TWAI_ALERT_ERR_PASS) {
    Serial.println("Alert: TWAI controller has become error passive.");
  }
  if (alerts_triggered & TWAI_ALERT_BUS_ERROR) {
    Serial.println("Alert: A (Bit, Stuff, CRC, Form, ACK) error has occurred on the bus.");
    Serial.printf("Bus error count: %lu\n", twaistatus.bus_error_count);
  }
  if (alerts_triggered & TWAI_ALERT_RX_QUEUE_FULL) {
    Serial.println("Alert: The RX queue is full causing a received frame to be lost.");
    Serial.printf("RX buffered: %lu\t", twaistatus.msgs_to_rx);
    Serial.printf("RX missed: %lu\t", twaistatus.rx_missed_count);
    Serial.printf("RX overrun %lu\n", twaistatus.rx_overrun_count);
  }

  // Check if message is received
  if (alerts_triggered & TWAI_ALERT_RX_DATA) {
    // One or more messages received. Handle all.
    twai_message_t message;
    while (twai_receive(&message, 0) == ESP_OK) {
      handle_rx_message(message);
    }
  }
}

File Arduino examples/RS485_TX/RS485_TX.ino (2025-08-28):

#define RXD1 18
#define TXD1 17

void setup() {
  // put your setup code here, to run once:
Serial2.begin(9600, SERIAL_8N1, RXD1, TXD1);
Serial.begin(9600);
Serial.write("Arduino Mega Serial1 test -  for loopback test connect pin 18 to pin 19\n");
  Serial.write("RS232: Mega pin 18 TXD to TTL/RD232 Tx and pin 19 RXD to TTL/RS232 Rx\n");
  Serial.write("RS232 - loopback connect 9-pin D-type pin 2 Tx to pin 3 Rx\n");
  delay(100);
}

void loop(){
  Serial2.write("gab\n");
    delay(300);
}

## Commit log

2025-06-01 Create kicad project files
2026-01-09 Add files via upload
    This is an intercative view of the board
